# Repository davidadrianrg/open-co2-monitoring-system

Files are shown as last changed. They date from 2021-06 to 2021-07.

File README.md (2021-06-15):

# open-co2-monitoring-system
CO2 monitoring system using ESP8266 as microcontroller and MH-Z19C as CO2 sensor, the data collected will be send to the cloud through MQTT protocol. In the cloud server the data will be managed by Node-Red, stored in an InfluxDB database and plot using Grafana service.

## Installation

### Flashing the microcontroller
Clone the repository using the following command.

```bash
git clone https://github.com/davidadrianrg/open-co2-monitoring-system.git
```
Create your secret `keys.h` file inside the folder `co2-sensor`, add your mqtt address and credentials in it like this.

```c++
//Configuration secret variables for the CO2 sensor
char brokerIP[15] = "ADD YOUR BROKER IP";
int brokerPort = 1883; //Or set another different than the default one
char mqtt_username[20] = "ADD YOUR MQTT USERNAME";
char mqtt_password[16] = "ADD YOUR MQTT PASSWORD";
```

Flash your ESP8266 microcontroller using Arduino IDE with the `co2-sensor.ino` file.

### Cloud services deployment

In your cloud instance, first install docker if you do not have installed it yet.

```bash
sudo apt update && apt install docker
```

Create a `.env` file to add the environment variables to config the containers described in `docker-compose.yaml`. Add the following to the file.

```.env
GF_PATHS_DATA=/var/lib/grafana
GF_PATHS_LOGS=/var/log/grafana
GF_SECURITY_ADMIN_USER=YOUR_GRAFANA_USER
GF_SECURITY_ADMIN_PASSWORD=YOUR_GRAFANA_PASSWORD

INFLUXDB_USERNAME=YOUR_INFLUXDB_USER
INFLUXDB_PASSWORD=YOUR_INFLUXDB_PASSWORD

MOSQUITTO_USERNAME=YOUR_MOSQUITTO_USER
MOSQUITTO_PASSWORD=YOUR_MOSQUITTO_PASSWORD
```

Create and start the containers with the services (Mosquitto, Node-Red, InfluxDB and Grafana). In the main folder of the project type the following.

```bash
sudo docker-compose up -d
```

Enjoy your IoT system!

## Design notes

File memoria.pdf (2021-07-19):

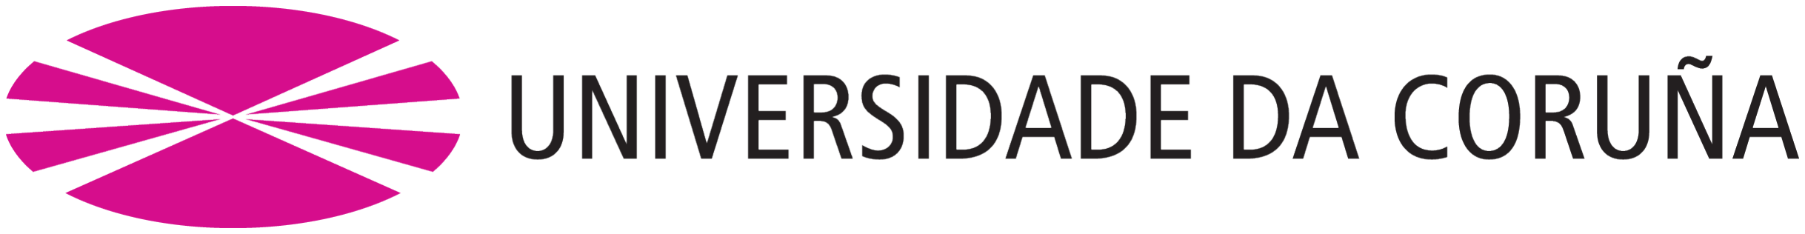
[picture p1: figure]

TÍTULO | DISENO DE SISTEMA DE MONITORIZACI ˜ | ON DE CALIDAD ´

### DEL AIRE EN LOCALES CON VENTILACION LIMITADA. ´

MASTER ´ | MASTER EN INFORM ´ | ATICA INDUSTRIAL Y ROB ´ | OTICA ´
ASIGNATURA | TRABAJO FIN DE MASTER (Nº 4538M01A001) ´
ALUMNO | DAVID ADRIAN RODR ´ | ÍGUEZ GARCÍA
TUTORES | FRANCISCO ZAYAS GATO
HECTOR QUINTI ´ | AN PARDO ´
FECHA | JUNIO DE 2021

## Índice

Resumen | 5
1 Introduccion´ | 6
1.1 Introduccion | ´ | 6
1.4.3 Computacion en la nube | ´ | 8
2 Monitorizacion de la calidad del aire | 10 ´
2.2 Principales parametros a controlar | ´ | 10
2.3 Sensores de medicion de CO2 | ´ | 11
3 Electronica y comunicaciones IoT | 15 ´
3.2 Esquema electronico de conexionado | ´ | 17
3.3 Programacion con Arduino | ´ | 18
3.3.3 Comunicacion UART con el sensor | ´ | 20
4 Arquitectura Cloud | 23

2

4.2.1 Arquitectura | 24
4.2.2 Docker | 24
4.3 Backend con Node-Red | 27
4.4 BBDD de series temporales | 29
4.5 Frontend | 30
4.5.1 Dashboards de visualizacion con Grafana | ´ | 30
4.5.2 Bot de notificaciones en Telegram | 31
5 Conclusiones y propuestas de mejora | 32
5.1 Conclusiones y resultados obtenidos | 32
5.2 Propuestas de mejora | 32
6 Referencias | 34
Anexos | 35
Presupuesto | 36

## Listado de figuras

1.1 Modelos de negocio de computacion en la nube | ´ | 9
2.1 Evolucion de la concentraci ´ | on de CO2 en un aula | ´ | 11
2.2 Tecnología NDIR en un sensor de CO2 | 12
3.1 Pinout NodeMCU V3 | 16
3.2 Esquema electronico de conexionado | ´ | | 17
3.3 Diagrama de Flujo del Programa Smart CO2 Sensor | 19
3.4 Portal Cautivo WiFiManager | 20
3.5 Conexionado bus UART | 20
3.6 Comunicacion MQTT | ´ | | 21
3.7 Carcasa impresa en 3D | 23
4.1 Arquitectura Cloud - Diagrama de despliegue | 25
4.2 Interfaces Docker | 25
4.3 Arquitectura Docker | 26
4.4 Diagrama de flujo en Node-Red | 28
4.5 Dashboard en Grafana | 30

3

4.6 Bot de alertas en Telegram | 31

## Listado de tablas

2.1 Comparativa de sensores comerciales de CO2 | 14
3.1 Pinout ESP-12F | 17
3.2 Conexionado de pines | 18
6.1 Listado de materiales empleados | 35
6.2 Presupuesto de prototipo de sensor inteligente de CO2 | 36

4

## Resumen

El presente Trabajo Fin de Master tiene por objetivo el dise ´ | no de un sistema de monitorizaci ˜ | on de ´
calidad del aire, a partir de hardware y sensorica de bajo coste. Se propone el uso de la plataforma ´
Arduino o similar junto con sensores de CO2, así como de algun sistema de centralizaci ´ | on local y/o en ´
la nube para almacenar y visualizar la informacion capturada. ´

## Resumo

O presente Traballo Final de Master ten por obxecto o dese ´ | no dun sistema de monitorizaci ˜ | on da ´
calidade do aire, a partir de hardware e sensorica de baixo custo. Proponse o uso da plataforma Arduino ´
ou similar xunto con sensores de CO2, así coma algun sistema de centralizaci ´ | on local e/ou na nube ´
para o almacenamento e visualizacion da informaci ´ | on recollida. ´

## Resumo

O objetivo desta Trabalho Final de Mestrado e projetar um sistema monitoramento da qualidade do ´ ar, com base em hardware e sensor de baixa custo. O uso da plataforma Arduino ou similar e proposto ´ em conjunto com sensores de CO2, bem como algum sistema de centralizaçao local e / ou na nuvem ˜ para armazenar e ver as informaçoes capturadas. ˜

## Abstract

The objective of this Master’s Thesis is to design an air quality monitoring system, based on low cost hardware and sensors. Using the Arduino platform or similar is proposed together with CO2 sensors, as well as some local and / or cloud centralization system to store and view the information captured.

5

## 1 Introduccion´

### 1.1 Introduccion´

El contexto socio-economico mundial ha cambiado recientemente a causa de la pandemia provo- ´
cada por el virus SARS-CoV-2 cuyo modo de infeccion y propagaci ´ | on es de tipo respiratorio. En esta ´
situacion, el control de la calidad del aire que respiramos en recintos cerrados ha cobrado especial ´ importancia para evitar la transmision del virus y asegurar el correcto desarrollo de la actividad social y ´ empresarial.
Este Trabajo Fin de Master pretende aportar una soluci ´ | on tecnol ´ | ogica y asequible enmarcada dentro ´
de la rama de desarrollo impulsada por los diferentes Estados para afrontar la recuperacion, la ´ | Digita-
lizacion e Industria 4.0 ´ | .
La propuesta tecnologica a desarrollar en esta memoria trata sobre el dise ´ | | | no de un sistema inteli- ˜
gente de monitorizacion de la calidad del aire bajo los principios del c ´ | | odigo libre y el hardware libre y de ´
bajo coste. Buscando con ellos el acceso a esta tecnología a escuelas, universidades, pequenas y me- ˜ dianas empresas, y demas espacios interiores que necesiten controlar la calidad de su aire interior para ´ con ello prevenir y mejorar la ventilacion de estos espacios y asegurar el correcto estado de salubridad ´ de sus instalaciones y de las personas que las frecuentan.

El desarrollo del proyecto se ha publicado de forma libre bajo licencia GNU General Public License
v3.0 que permite su modificacion y difusi ´ | on respetando su continuaci ´ | on como c ´ | odigo abierto al p ´ | ublico. ´
Puede accederse al repositorio publico a trav ´ | es de la siguiente referencia [ ´ | 8].

### 1.2 Objetivos

Los objetivos que se plantean para este Trabajo Fin de Master consisten en el desarrollo de un ´
sistema de monitorizacion de la calidad del aire mediante la utilizaci ´ | on de hardware y sensores de ´
bajo coste así como haciendo uso de servicios de software libre para el tratamiento, visualizacion y ´ almacenamiento de los datos.
De esta forma, se desarrollara una soluci ´ | on econ ´ | omica que permitir ´ | a a diferentes escuelas, oficinas ´
y otros recintos cerrados controlar en todo momento la concentracion de CO2 en el aire, con el objetivo ´
de mejorar la ventilacion de dichos recintos y reducir con ello las probabilidades de transmisi ´ | on de en- ´
fermedades respiratorias y el agotamiento que produce una insuficiente calidad en el aire que respiran las personas.

### 1.3 Alcance

El alcance de este Trabajo Fin de Master comprende el dise ´ | no de un sistema de monitorizaci ˜ | on de ´
la calidad de aire basado las siguientes tecnologías y procesos:
Analisis de los par ´ | ametros del aire a monitorizar. ´

Estudio de mercado y seleccion del mejor sensor calidad-precio. ´

6

Programacion y montaje del prototipo de sensor de CO2 inteligente mediante hardware de bajo ´ coste e impresion 3D. ´

Despliegue y configuracion de los servicios backend en la nube para la recogida, an ´ | alisis y trata- ´
miento de los datos enviados por el sensor.

Analisis de los resultados obtenidos y propuestas de mejora del producto de cara a una posible ´ version comercial del mismo. ´

### 1.4 Antecedentes

El sensor de CO2 inteligente de este proyecto aglutina el uso de diferentes tecnologías en un mismo producto, en concreto combina el uso de la plataforma Arduino para programacion y como estandarte ´ del hardware de bajo coste, el empleo de comunicaciones IoT que permiten interconectar gran cantidad
de objetos cotidianos a internet y la computacion en la nube como soluci ´ | on que permite acceder a ´
las ventajas del uso de servidores sin disponer de infraestructura propia, reduciendo notablemente los costes, limitandolos al pago por uso de los recursos. ´

### 1.4.1 Plataforma Arduino

Arduino es una plataforma de hardware-libre y codigo abierto utilizada para construir proyectos de ´
electronica y para el prototipado r ´ | apido de productos. La plataforma cuenta con una gran comunidad de ´
usuarios que respaldan el proyecto y lo alimentan con una amplia variedad de librerías y ports de otros microcontroladores a esta plataforma, como el caso de los microcontroladores para el IoT de Espressif Systems.

La empresa Arduino aporta valor al mercado en dos aspectos, en primer lugar, el desarrollo de placas PCB que contienen todo lo necesario para desarrollar prototipos de electronica a un coste muy ´
bajo, la mas popular es el modelo ´ | Arduino UNO lanzado inicialmente en su primera version en el a ´ | nõ
2010, aunque el primer modelo de la compan˜ía el Arduino Serie fue lanzado en 2005.

En segundo lugar, la compan˜ía se encarga del mantenimiento y desarrollo del popular IDE de Arduino que permite la programacion de todas su placas y las de otros fabricantes que hayan portado sus ´ librerías a este entorno de desarrollo. El lenguaje de programacion utilizado es una variante de C/C++ ´
que solo requiere un mínimo de dos funciones basicas para funcionar, la funci ´ | on´ setup que se ejecuta
una sola vez al encenderse la placa y la funcion´ loop que se repite constantemente mientras la placa este encendida. ´

Esta plataforma ha servido y sirve como base para muchos de los proyectos de electronica que han ´
surgido en los ultimos 10 a ´ | nos, incluido el descrito en esta memoria. ˜

### 1.4.2 Internet de las Cosas

El concepto de Internet de las Cosas o en ingles´ Internet of Things (IoT) surgio en el a ´ | no 1999 ˜
en el MIT en el campo de la identificacion por radiofrecuencia (RFID), pero hoy en d ´ | ía es un termino ´
mucho mas amplio que comprende gran cantidad de objetos que pueden ampliar sus funcionalidades ´ mediante una conexion a la red. En este sentido han salido al mercado todo tipo de dispositivos como ´ lavadoras, neveras, bombillas, termostatos, etc. denominados inteligentes que permiten su telegestion´ desde cualquier lugar a traves de internet. ´

7

El internet de las cosas presenta aplicacion en multitud de campos diferenciados, desde controlar ´ mediante sensores el campo en la agricultura para conseguir las condiciones idoneas de humedad, luz, ´
temperatura, etc. hasta sistemas mas complejos como el Autom ´ | ovil Conectado que cuenta con un gran ´
numero de sensores que env ´ | ían informacion en tiempo real sobre el estado del veh ´ | ículo (aceleracion, ´
velocidad, nivel de combustible, ubicacion, etc.). ´
En un mundo cada vez mas digital el auge del internet de las cosas contin ´ | ua su crecimiento de ´
forma exponencial, cada días mas dispositivos se conectan a la red por lo que la tecnolog ´ | ía debe seguir
avanzando para garantizar la seguridad de las comunicaciones y la mejora de las mismas, mediante nuevos protocolos y nuevos sistemas de telecomunicaciones como el 5G.

### 1.4.3 Computacion en la nube ´

Se entiende por computacion en la nube ´ | como un paradigma en el que se ofrecen servicios de
computo inform ´ | aticos mediante un modelo de negocio en el que se paga por uso, se solicita el uso de ´
recursos informaticos, principalmente almacenamiento de datos y capacidad de c ´ | omputo en un centro ´
de datos que se encuentran disponibles a traves de internet. ´

Dentro de este amplio concepto, existen otros tres que se han vuelto muy populares en los ultimos ´ anos: ˜

Infraestructura como servicio (IaaS), es el modelo de pago por uso de servicios informaticos de ´ procesamiento, almacenamiento y redes en los servidores de centros de datos del proveedor del servicio.

Plataforma como servicio (PaaS), es similar al IaaS pero con una capa superior de abstraccion, ´ ademas de la infraestructura, el servicio contratado ofrece otras herramientas como middlewares, ´ sistemas de Business Intelligence, sistemas de administracion de bases de datos y el sistema ´ operativo y diferentes aplicaciones o librerías que son necesarias para el despliegue de la aplicacion. ´

Software como servicio (SaaS), es un modelo de distribucion de software en el que el c ´ | odigo ´
y los datos se almacenan en un servidor en la nube y el usuario accede al servicio a traves de ´ internet. Normalmente el software puede ser consultado desde cualquier dispositivo a traves de ´ un navegador web.

Las aplicaciones mas modernas comienzan a ser desarrolladas entorno a estos paradigmas men- ´ cionados, y los modelos de negocio cambian de la venta de licencias tradicional a las suscripciones por uso del servicio (SaaS). La figura 1.1 muestra las diferencias entre los 3 conceptos anteriores.

### 1.4.4 Medidores de CO2 de referencia

Se ha tenido en cuenta como referencia para la realizacion de este proyecto, algunos de los medi- ´ dores de CO2 que se venden actualmente en el mercado.

Uno de ellos ha sido el modelo PCE-CMM 5 [9] de la empresa PCE Instruments, se trata de un modelo de medidor de CO2 con pantalla LCD y tecnología NDIR, muestra los valores de concentracion´ de CO2, temperatura y humedad por dicha pantalla pero no dispone de comunicacion con internet a ´ diferencia del prototipo a disenar en esta memoria. ˜

8

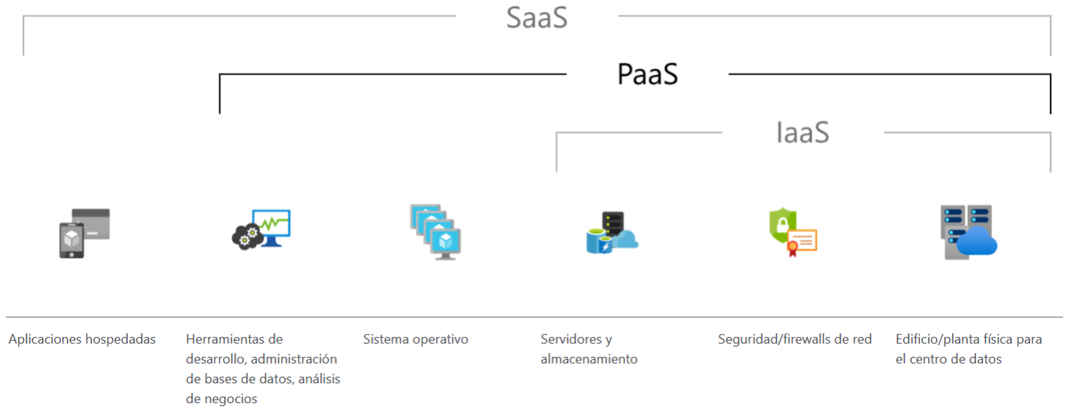
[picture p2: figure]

Figura 1.1: Modelos de negocio de computacion en la nube ´

En cuanto a medidores de referencia conectados a internet, existen varios proyectos que circulan por la red a cerca de medidores de CO2 con conexion por internet, entre ellos se ha tomado como ´
referencia especialmente el proyecto CODOS [12] de Miguel Angel Casanova que da una soluci ´ | on´

similar a la aquí planteada utilizando hardware de bajo coste y un portal cautivo para la visualizacion´
de los valores medidos, aunque sin utilizar los servicios cloud que se comentaran en el apartado ´ | 4.2.1
y que sera la mayor innovaci ´ | on del proyecto descrito en esta memoria. ´

### 1.5 Estructura del TFM

La estructura se divide en capítulos para tratar de alcanzar en ellos los objetivos descritos previamente.

En el capítulo 2 se presentan los diferentes motivos que impulsan este Trabajo Fin de Master en ´
relacion con la monitorizaci ´ | on de la calidad del aire y los beneficios que ´ | esta puede tener sobre la salud ´
de las personas, ademas se comentar ´ | an los principales par ´ | ametros a controlar y se realizar ´ | a un an ´ | alisis ´
del mercado de sensores de CO2 y la seleccion del m ´ | as apropiado para este proyecto. ´

En el capítulo 3 se describe el microcontrolador utilizado para la programacion del sensor inteli- ´
gente y los motivos de su eleccion, adem ´ | as se desarrollan las explicaciones y esquemas necesarios ´
para el conexionado de los diferentes componentes que conformaran dicho sensor inteligente. Tam- ´
bien se explicar ´ | a el funcionamiento del programa desarrollado para dicho microcontrolador y el tipo de ´
comunicaciones IoT utilizadas.

En el capítulo 4 se aborda la arquitectura del servidor en la nube necesario para la recogida, alma-
cenamiento y visualizacion de los datos enviados por el sensor, se explicar ´ | an los diferentes servicios y ´
metodos de despliegue utilizados. ´

En el capítulo 5 se comentan los resultados obtenidos a lo largo de todo el proyecto realizado, se proponen una serie de mejoras sobre el prototipo que podrían incluirse en un producto comercial final y se resumen las conclusiones mas importantes obtenidas de este proyecto. ´

9

## 2 Monitorizacion de la calidad del aire ´

### 2.1 Beneficios del control de la calidad del aire

La monitorizacion y control de la calidad de aire en locales cerrados presenta diferentes benefi- ´
cios para la salud de las personas, en particular se tratara dicha monitorizaci ´ | on en aulas de colegios, ´
institutos o universidades, pues se busca la utilidad del sistema proyectado como medida de monitori-
zacion del aire y prevenci ´ | on de enfermedades respiratorias como el ´ | COVID-19 en las instalaciones de
la Universidade da Corunã .
La informacion recogida en esta secci ´ | on ha sido obtenida del documento oficial elaborado por el ´
CSIC-IDAEA, Ministerio de Ciencia e Innovacion y Mesura ´ | [11] y plantea estrategias para indicar las
condiciones de ventilacion adecuadas en las aulas, as ´ | | í como una serie de características deseables en
los medidores de CO2 a utilizar para la monitorizacion de la calidad del aire. ´
La concentracion de CO2 en espacios interiores cerrados aumenta r ´ | | apidamente en presencia de ´
personas, que exhalan al respirar. La renovacion del aire con aire exterior reduce las concentraciones ´
de CO2 en el interior. Esto favorece la atencion y rendimiento escolar, ya que la exposici ´ | on a concen- ´
traciones de CO2 demasiado elevadas produce aletargamiento y dificulta la atencion. ´

Por ello es necesario garantizar la correcta renovacion del aire del aula para disminuir la concen- ´
tracion de CO2 y otras part ´ | | ículas infecciosas como los virus. Para medir la renovacion de aire en un ´
espacio cerrado se utiliza el termino ACH ´ | Air Changes per Hour que indica que en 1 hora entra en la
sala una cantidad de aire igual al volumen de la misma.

Una medida recomendable para el ACH es de 14 litros por persona y segundo que se puede transformar a renovaciones por hora mediante la siguiente expresion. ´

| ACH =

litros

persona·segundo · npersonas · 3600 seg h

- 0.001 m³ litros·Vsala

Teniendo en cuenta que la concentracion de CO2 es aproximadamente de 420 ppm en ambientes ´ exteriores, y que se entiende como de cierto riesgo sobrepasar los valores de 1000 ppm en un espacio cerrado, la figura 2.1 muestra un ejemplo de la variacion de CO2 en un aula con 21 alumnos y un ´
metodo de ventilaci ´ | on natural con ventilaci ´ | on cruzada (apertura de puertas y ventanas opuestas) que ´
es la que se presenta en la mayoría de las aulas.
Como conclusion obtenida de la gr ´ | afica vemos que utilizando adecuadamente la ventilaci ´ | on en el ´
momento oportuno se puede evitar sobrepasar el valor de riesgo de 1000 ppm de concentracion de ´
CO2. Teniendo esto en cuenta, el objetivo de este Trabajo de Fin de Master ser ´ | a desarrollar un sensor ´
de CO2 inteligente que notifique a los usuarios de la sala mediante graficas en tiempo real y un chat ´
de mensajería, de esta forma podra preveerse el aumento de la concentraci ´ | on de CO2 y actuar con ´
anterioridad para estabilizar dicha concentracion en valores saludables para las personas. ´

### 2.2 Principales parametros a controlar ´

Como se ha comentado en el apartado 2.1 la medicion de la concentraci ´ | on de CO2 es el principal ´
parametro a controlar en un sistema de monitorizaci ´ | | on de la calidad de aire, pues permite calcular a ´
partir de ella las renovaciones hora del espacio.

10

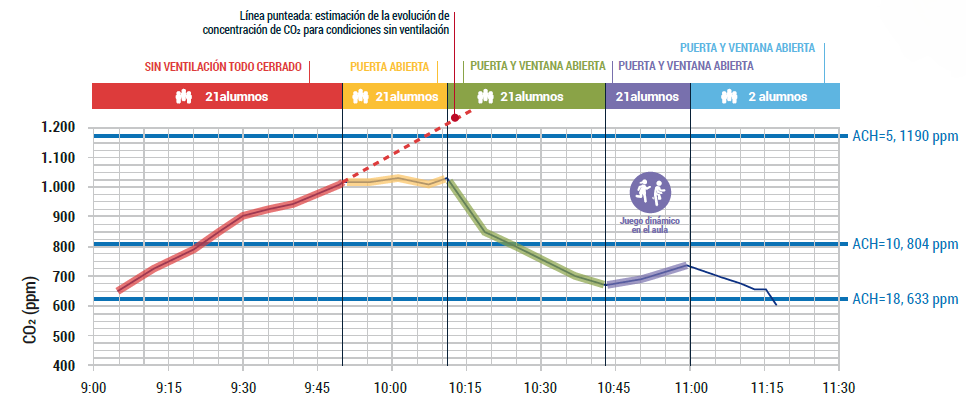
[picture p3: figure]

Figura 2.1: Evolucion de la concentraci ´ | on de CO2 en un aula ´
Como parametros adicionales interesantes que afectan al confort en un espacio interior se podr ´ | ía
realizar la medicion de las condiciones de temperatura y humedad del ambiente, y de esta forma tratar ´
de garantizar el compromiso ideal entre la ventilacion realizada y el confort t ´ | ermico para las personas, ´
evitando, por ejemplo, una ventilacion natural excesiva que provoque una fuerte ca ´ | ída en la temperatura
de la sala.

Tambien es conveniente destacar que el CO2 no se degrada con el tiempo, mientras que los virus ´
en aire sí, por lo que las concentraciones de virus en aire decreceran m ´ | as r ´ | apidamente que las de CO2. ´
La diferencia depende de varios factores ambientales, tales como radiacion UV o temperatura. Por lo ´
que utilizar la concentracion de CO2 como medida para cuantificar las necesidades de ventilaci ´ | on de ´
un espacio es conservador y permite garantizar la correcta calidad del aire en la sala.

Con referencia a lo aquí mencionado se estudiara el mercado de sensores de CO2 que existe ´
en la actualidad y se tratara de seleccionar el que mejor se adapte en relaci ´ | on calidad-precio a las ´
características mencionadas en el apartado 2.3.

### 2.3 Sensores de medicion de CO2 ´

En este apartado se realizara un estudio de mercado acerca de los diferentes sensores de CO2 ´ existentes para desarrollo/prototipado analizando sus características tanto para el tipo de medicion de ´ CO2 que realizan como sus interfaces de comunicaciones con el microcontrolador y el rango de precio
en el que se situan. Estas caracter ´ | ísticas seran comparadas con las recomendadas en el art ´ | ículo [11]
para medidores de CO2 en aulas y son las siguientes:

Capacidad de proporcionar los datos sin procesar descargables en archivo .txt, .xls, .csv o similar.

Resolucion temporal de al menos un dato por minuto ´

Pantalla que muestre los niveles de CO2 en tiempo real

Uso de tecnología NDIR (del ingles nondispersive infrared) ´

Coste entre 100 y 300 C

11

Estas características antes mencionadas hacen referencia a un medidor de CO2 comercial, el ob-
jetivo de este proyecto es aportar una solucion diferente y m ´ | as innovadora, a ´ | nadiendo conectividad al ˜
sensor de CO2 y un conjunto de servicios en la nube para el procesado, almacenamiento y visualizacion´ en tiempo real de los valores de concentracion medidos. Por lo que aunque han de tenerse en cuenta ´ las características mencionadas, no se seguiran al pie de la letra a la hora de seleccionar el sensor a ´ utilizar.

Del estudio de mercado realizado se han seleccionado los sensores de CO2 mas representativos, ´
listando en la tabla 2.1 sus diferentes características tecnicas para su comparaci ´ | on. ´

Existen principalmente 2 tipos de tecnologías que permiten medir la concentracion de CO2 en al ´ aire ambiente, se trata de las tecnologías NDIR (Non Dispersive Infrared) y MOS (Metal Oxide Semi-
conductor) que se describiran a continuaci ´ | on. ´

La tecnología NDIR realiza la medicion directa del CO2 mediante un haz de luz infrarroja en el interior ´ de la camara de aire del sensor, el CO2 absorbe una determinada longitud de onda del infrarrojo y de ´ esta forma el detector de infrarrojos con el que cuenta el sensor es capaz de filtrar el resto de longitudes de onda de la luz y medir la intensidad de la longitud de onda que absorbe la molecula de CO2 para ´
con ello obtener su concentracion. La figura ´ | 2.2 muestra el proceso descrito.

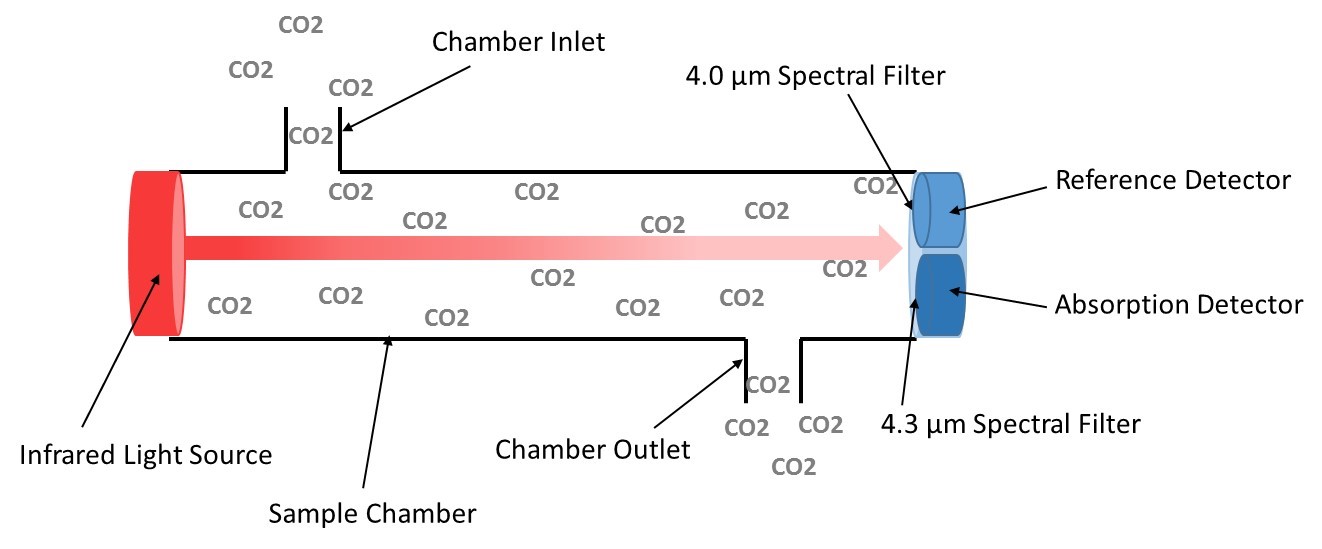
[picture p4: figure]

Figura 2.2: Tecnología NDIR en un sensor de CO2

En cambio la tecnología MOS se basa en la medicion de los compuestos org ´ | anico vol ´ | atiles (VOC) ´
del aire por oxidacion de un semiconductor de ´ | oxido de metal, y con ellos pueden calcular de forma ´
indirecta la concentracion de CO2 en el aire, por lo que su precisi ´ | on es m ´ | as baja, y depende mucho ´
de los valores de temperatura y humedad a la hora de realizar dicho calculo lo que implica que deben ´ acompanarse de un sensor externo de Tª y Humedad que suministre dichos valores al sensor MOS. ˜
Las ventajas de los sensores MOS es que suelen ser mas baratos que los NDIR, de menor tama ´ | nõ
y menor consumo. En cambio los sensores NDIR ofrecen una medida del CO2 mas precisa aunque ´
tambien su consumo, coste y tama ´ | no es mayor. ˜

Dado que entre las características que se tendran en cuenta para este proyecto el consumo no ´ es relevante pues el microcontrolador WiFi que se utilizara para comunicar los datos tiene un elevado ´
consumo debido al protocolo WiFi, se optara entonces por dise ´ | nar un medidor de CO2 inteligente ˜
con alimentacion directa de la red. En el caso de optar por soluciones inal ´ | ambricas con bater ´ | ía sería
necesario utilizar otro protocolo de menor consumo como Zigbee o BLE (Bluetooth Low Energy).

12

El tamano, aunque importante para un futuro producto final, no es demasiado relevante en este ˜ prototipo y tampoco sería crítico en un producto final, ya que se busca un producto que se ubicara de ´ forma estatica en una sala y no es necesaria demasiada portabilidad del mismo. ´

El coste sí es importante pues en general para la monitorizacion de la calidad de aire de una escuela ´ o universidad sería necesario contar con al menos uno por aula, por lo que reducir al maximo los costes ´ supondría una mayor posibilidad de aceptacion del producto hacia este segmento de clientes objetivo. ´

La precision en la medici ´ | on juega un papel clave a la hora de seleccionar el tipo de tecnolog ´ | ía del
sensor, lo que se busca es la prevision de la concentraci ´ | on de CO2 con anterioridad y un correcto control ´
de su evolucion en funci ´ | on de la ventilaci ´ | on realizada por lo que es necesaria una buena precisi ´ | on que ´
garantice una correcta correlacion entre la concentraci ´ | on y el uso de la ventilaci ´ | on. ´

Teniendo en cuenta todas estas características descritas y el estudio de mercado realizado y recogido en la tabla 2.1 se ha decidido seleccionar para este proyecto el modelo de sensor de tecnología NDIR MH-Z19c de la marca Winsen pues permite asegurar una correcta relacion calidad-precio. ´

13

Fabricante Modelo Tecnología Rango Efectivo Precisión Interfaz Tiempo de respuesta Sensores Precio

Amphenol T6713 NDIR 400-2000 ppm ± (25 ppm + 3 %) UART, I2C, PWM <180 s (90 %) CO2 48.19 - 70.99 C

Amphenol T6713-5K NDIR 400-5000 ppm ± (30 ppm + 3 %) UART, I2C, PWM <180 s (90 %) CO2 51.46 - 70.99 C

Cubic CM1106-C NDIR 400-5000 ppm ± (50 ppm + 5 %) UART, I2C, PWM 30 s CO2

Cubic CM1106SL-NS NDIR 400-5000 ppm ± (50 ppm + 5 %) UART 120 s CO2

Gas Sensing Sol. COZIR-AH-E-1 NDIR 400-10000 ppm ± (30 ppm + 3 %) UART 30 s (90 %) CO2, H, T 73.78 - 100.14 C

Gas Sensing Sol. COZIR-LP-5000 NDIR 400-5000 ppm ± (30 ppm + 3 %) UART 30 s (90 %) CO2 63.41 - 86.06 C

Honeywell CRIR M1 NDIR 400-2000 ppm ± (40 ppm + 3 %) UART 120 s CO2 39.48 - 51.34 C

SenseAir S8 LP NDIR 400-2000 ppm ± (40 ppm + 3 %) UART, PWM <120 s (90 %) CO2 23.17 - 36.42 C

SenseAir Sunrise NDIR 400-5000 ppm ± (30 ppm + 3 %) UART, I2C 16 s CO2 44.84 C

Sensirion SCD-41 NDIR 400-5000 ppm ± (40 ppm + 5 %) I2C 60 s (63 %) CO2, H, T 42.94 C

Sensirion SCD-30 NDIR 400-10000 ppm ± (30 ppm + 3 %) UART, I2C, PWM 20 s (63 %) CO2, H, T 30.57 - 44.47 C

Winsen MH-Z19B NDIR 400-5000 ppm ± (50 ppm + 5 %) UART, PWM <120 s (90 %) CO2 18.61 C

Winsen MH-Z19C NDIR 400-5000 ppm ± (50 ppm + 5 %) UART, PWM <120 s (90 %) CO2 17.09 C

ZyAura (Radiant) ZG09 NDIR 400-10000 ppm ± (50 ppm + 3 %) UART, I2C, PWM 60s CO2 27.11 C

Adafruit AMS CCS811 MOS 400-8192 ppm ± 2 % I2C 250ms - 60s CO2 24 C

Sparkfun SEN-16531 MOS 400-60000 ppm ± 1 % I2C 1s CO2 20 C

Keystudio AMS CCS811 MOS 400-8192 ppm ± 2 % I2C 250ms - 60s CO2 15 C

Sparkfun SEN-14348 MOS 400-8192 ppm ± 2 % I2C 250ms - 60s CO2, H, T 29 C

Tabla 2.1: Comparativa de sensores comerciales de CO2

14

### 2.3.1 Sensor MH-Z19C

El sensor de la empresa China Zhengzhou Winsen Electronics Technology Co., Ltd en concreto el modelo MH-Z19c es el que se ha seleccionado dada su alta relacion calidad-precio. ´

Se trata de un sensor que utiliza la tecnología NDIR, con un rango efectivo entre 400 ppm y 5000
ppm, que cubre perfectamente la aplicacion para la que est ´ | a destinado, lo mismo sucede con la pre- ´
cision ± (50 ppm + 5 %), la interfaz de comunicaci ´ | on es UART y cuenta con multitud de librer ´ | ías que
facilitan el desarrollo de codigo para el entorno Arduino, como se explicar ´ | a en la secci ´ | on´ 3.3.3, ademas´
tambien presenta la interfaz de comunicaci ´ | on PWM aunque no se usar ´ | a en este proyecto. ´
Como puntos mas negativos del sensor es que s ´ | olo cuenta con sensor de CO2, no incluye de hume- ´
dad y temperatura, pero puede calcular la temperatura de forma indirecta en funcion de la concentraci ´ | on´
de CO2 medida. Ademas el tiempo de respuesta del sensor es de 120 segundos, el doble de lo reco- ´
mendado en 2.3, este ser ´ | a el par ´ | ametro limitante a la hora de seleccionar el tiempo de muestreo en el ´
programa del microcontrolador.

En general sopesando todas las características y teniendo muy en cuenta su principal ventaja, el
precio, es el sensor NDIR mas barato del mercado, apenas unos 17,09 ´ | C, es el sensor ideal para un
producto que pretende dar una solucion econ ´ | omica, innovadora y precisa para el control de la calidad ´
de aire en las aulas de escuelas y universidades.
Una documentacion m ´ | as extensa acerca de las caracter ´ | ísticas tecnicas del sensor puede encon- ´
trarse en la ficha tecnica del fabricante [ ´ | 6].

## 3 Electronica y comunicaciones IoT ´

### 3.1 Placa de desarrollo NodeMCU V3

La placa electronica PCB encargada de hacer “inteligente” el sensor de CO2 seleccionado en el ´ apartado 2.3.1, se trata de una placa NodeMCU V3 que es una plataforma IoT de codigo abierto y ´ hardware libre que incluye el SoC ESP8266 de la empresa Espressif Systems.

NodeMCU surgio inicialmente como un kit de desarrollo para el prototipado de dispositivos ´ | IoT me-
diante el lenguaje de scripting LUA, posteriormente al desarrollo de la portabilidad del core de Arduino
para ESP8266, NodeMCU amplio su compatibilidad con ´ | este entorno de desarrollo, que es el que utili- ´
zaremos para este proyecto como se describe en la seccion´ 3.3.

La placa cuenta con el SoC ESP8266 como chip principal, con sus correspondientes GPIOs ma-
peados a las entradas/salidas digitales y la entrada analogica de la placa que se mencionar ´ | an m ´ | as en ´
detalle en el apartado 3.1.1, cuenta tambien con una interfaz micro USB para su programaci ´ | on y ali- ´
mentacion, adem ´ | as del regulador de tensi ´ | on que permite alimentarlo a 5V desde el micro USB o hasta ´
12V desde el pin Vin. Cuenta tambien con un pin de salida ´ | VU conectado directamente a la tension del ´
micro USB por lo que podría resultar muy util para alimentar directamente sensores o actuadores que ´ funcionen a 5V en lugar de los 3.3V de operacion del SoC. ´

Como conversor de USB a interfaz serie para programar el SoC la placa incluye el chip FTDI modelo CH340, la siguiente figura 3.1 muestra el pinout de la placa.

15

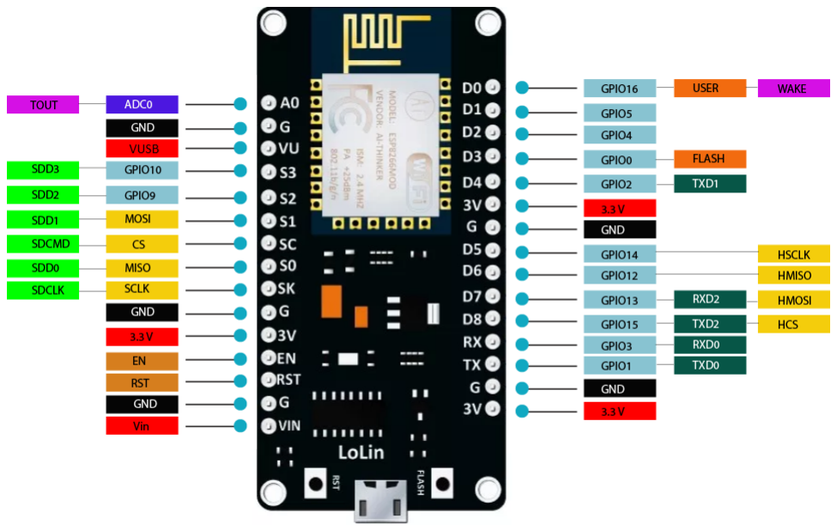
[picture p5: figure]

Figura 3.1: Pinout NodeMCU V3

### 3.1.1 Microcontrolador ESP8266

El microcontrolador ESP8266 se ha convertido en uno de los SoC (System on Chip) mas populares ´ en el sector del Internet de las Cosas, desde su lanzamiento en el ano 2014 por la empresa china ˜ Espressif Systems, numerosos productos comerciales lo han incorporado como base para dispositivos inteligentes, y existen en internet gran cantidad de soluciones profesionales y maker que utilizan este microcontrolador como base para sus proyectos.

Algunas de las características que han garantizado su exito son: ´

Conexion WiFi con stack TCP/IP completo. ´

Programacion desde el entorno de Arduino. ´

Muy bajo coste, entre 1-3 C dependiendo del modelo.

Diferentes versiones con mejoras en memoria y numero de GPIOs. ´

Lo incorporan una gran variedad de kits de desarrollo.

El modelo que incorpora la placa de desarrollo NodeMCU V3 utilizada para este proyecto es el ESP-12F desarrollado por la empresa china Ai-Thinker Technology el cual encapsula el chip ESP8266 core.

Los pines que incluye el chip mencionado son los que recoge la tabla 3.1.

El tipo de empaquetado que utiliza es SMD22 y la memoria flash de la que dispone es de 32 MB
(MegaBytes). Para una mayor descripcion de las caracter ´ | ísticas del chip acuda la ficha tecnica del ´
fabricante [5].

16

Tipo de pin | Numeracion | Unidades ´
GPIO | GPIO0 - GPIO16 | 16
UART | TX0 - RX0 | 1 (2 pines)
ADC (10bit) | A0 | 1
SPI | GPIO12(HMISO), GPIO13(HMOSI), GPIO14(HSCLK), GPIO15(HCS) | 1 (4 pines)
RESET | RST | 1
ENABLE | EN | 1
POWER | GND-VCC | 1 (2 pines)

Tabla 3.1: Pinout ESP-12F

### 3.2 Esquema electronico de conexionado ´

La configuracion de hardware necesaria para llevar a cabo el proyecto de sensor de CO2 inteligente, ´
requiere la utilizacion de los siguientes m ´ | odulos hardware interconectados: ´

Placa de desarrollo NodeMCU V3

Sensor de CO2 modelo Winsen MH-Z19c

Modulo de alimentaci ´ | on MB-102 ´
La utilizacion del m ´ | odulo de alimentaci ´ | on, aunque no es imprescindible para este proyecto al contar ´
con el pin VU se ha decidido utilizar para aportar una mayor conectividad en la alimentacion (interfaz ´
USB y jack) y la disponibilidad de un boton para encender/apagar la alimentaci ´ | on. Adem ´ | as este m ´ | odulo ´
permite salida de voltaje a 5V y 3,3V por lo que es compatible con todo tipo de sensores y actuadores que puede manejar el microcontrolador ESP8266.

El esquema de conexionado de los componentes sería el indicado por la figura 3.2

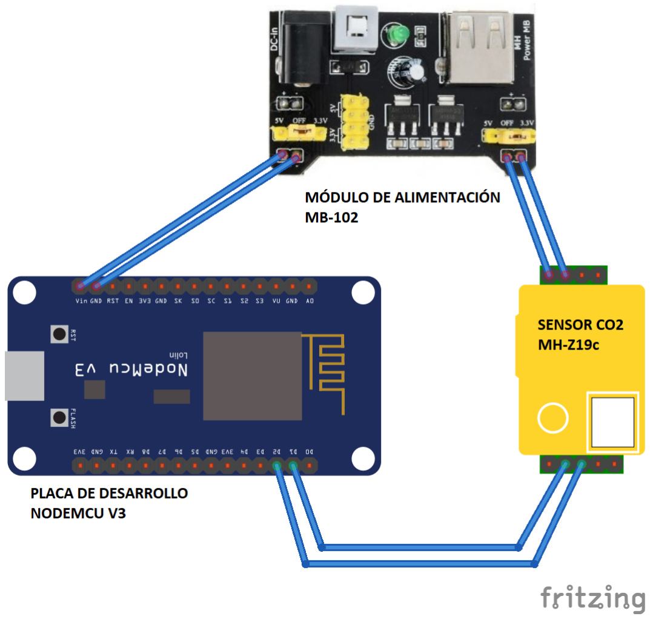
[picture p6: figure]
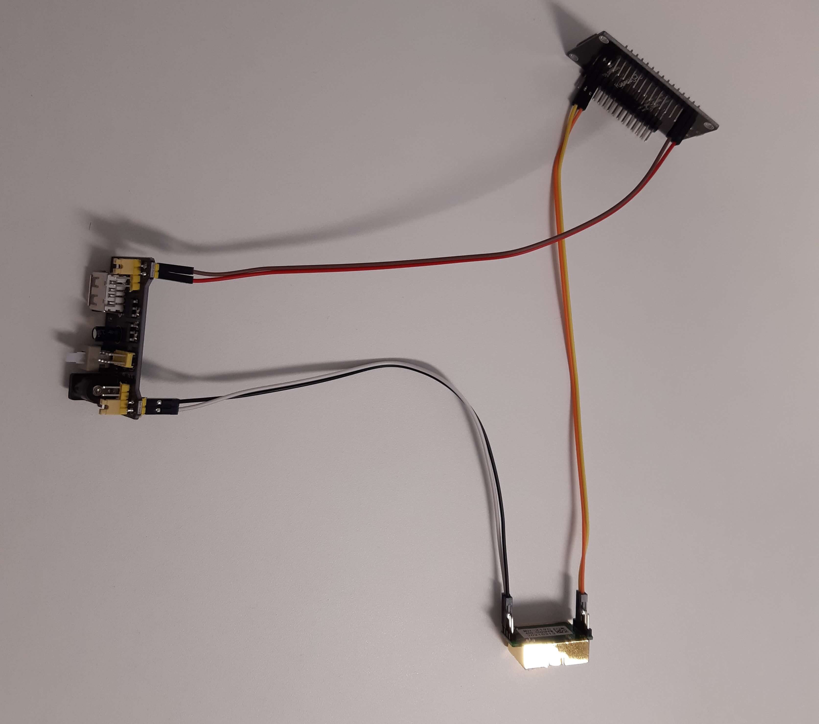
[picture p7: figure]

Figura 3.2: Esquema electronico de conexionado ´

El modulo de alimentaci ´ | on presenta dos salidas configurables a 5V o 3,3V mediante un conector ´
jumper, en este caso se configuraran las dos a 5V pues el regulador de voltaje de la placa NodeMCU ´

17

requiere como mínimo 5V y la alimentacion por el pin ´ | Vin se realiza a traves de dicho regulador. Por ´
tanto el conexionado queda como indica la tabla 3.2.
Modulo | Pines | M ´ | odulo | Pines ´
MB-102 | +, - (5V) | NodeMCU | Vin, GND
MB-102 | +, - (5V) | MH-Z19c | Vin, GND
NodeMCU | D1(TX), D2(RX) | MH-Z19c | RX, TX

Tabla 3.2: Conexionado de pines

### 3.3 Programacion con Arduino ´

### 3.3.1 Funcionamiento

La programacion del microcontrolador se llevar ´ | a a cabo mediante el framework de Arduino, pues el ´
core del microcontrolador que se ha utilizado, el Espressif ESP8266, ha sido portado a Arduino con una compatibilidad muy alta en cuanto a librerías y funcionalidades en relacion con el Arduino Core. Por ´ ello, las facilidades de programacion de este microcontrolador lo han convertido en todo un referente ´ para el desarrollo de dispositivos en el sector del Internet de las cosas.

Para la programacion que se ha llevado a cabo en este prototipo de sensor de CO2 y Temperatura ´ inteligente se ha tenido en cuenta la inclusion de las siguientes funcionalidades: ´

Comunicacion serie con el sensor mediante UART. ´

Comunicacion serie con el PC para depuraci ´ | on de c ´ | odigo. ´
Configuracion din ´ | amica de las credenciales WiFi. ´
Funcion de autocalibraci ´ | on del sensor activada. ´
Conexion con broker MQTT y reconexi ´ | on en caso de p ´ | erdida de la comunicaci ´ | on. ´

Toma de medidas y envío de datos por MQTT en bucle cada tiempo de muestreo.

La figura 3.3 muestra un diagrama de flujo del programa co2-sensor.ino. (https://github.com/davidadrianrg/open-co2-monitoring-system/blob/master/co2-sensor/co2-sensor.ino)

### 3.3.2 Librería WiFiManager

Uno de los problemas que presentan la programacion del microcontrolador ESP8266 es la confi- ´
guracion de las credenciales de acceso a internet, de conexi ´ | on WiFi con el router, habitualmente esta ´
configuracion suele establecerse directamente en el propio fichero del programa con el consecuente ´ inconveniente de que en caso de modificarse el ssid o la contrasena de la red WiFi, o simplemente de ˜ mover el microcontrolador a un lugar con otra red, es necesario volver a flashear el programa con las nuevas credenciales de conexion WiFi. ´

Para solucionar el problema mencionado, y con el objetivo de aproximarnos mejor a un producto
comercial, se implementara en el programa la librer ´ | ía WiFiManager[10] que permite la configuracion´
dinamica de las credenciales WiFi sin modificar el programa. ´

Los pasos que sigue la librería para establecer la conexion WiFi son: ´

18

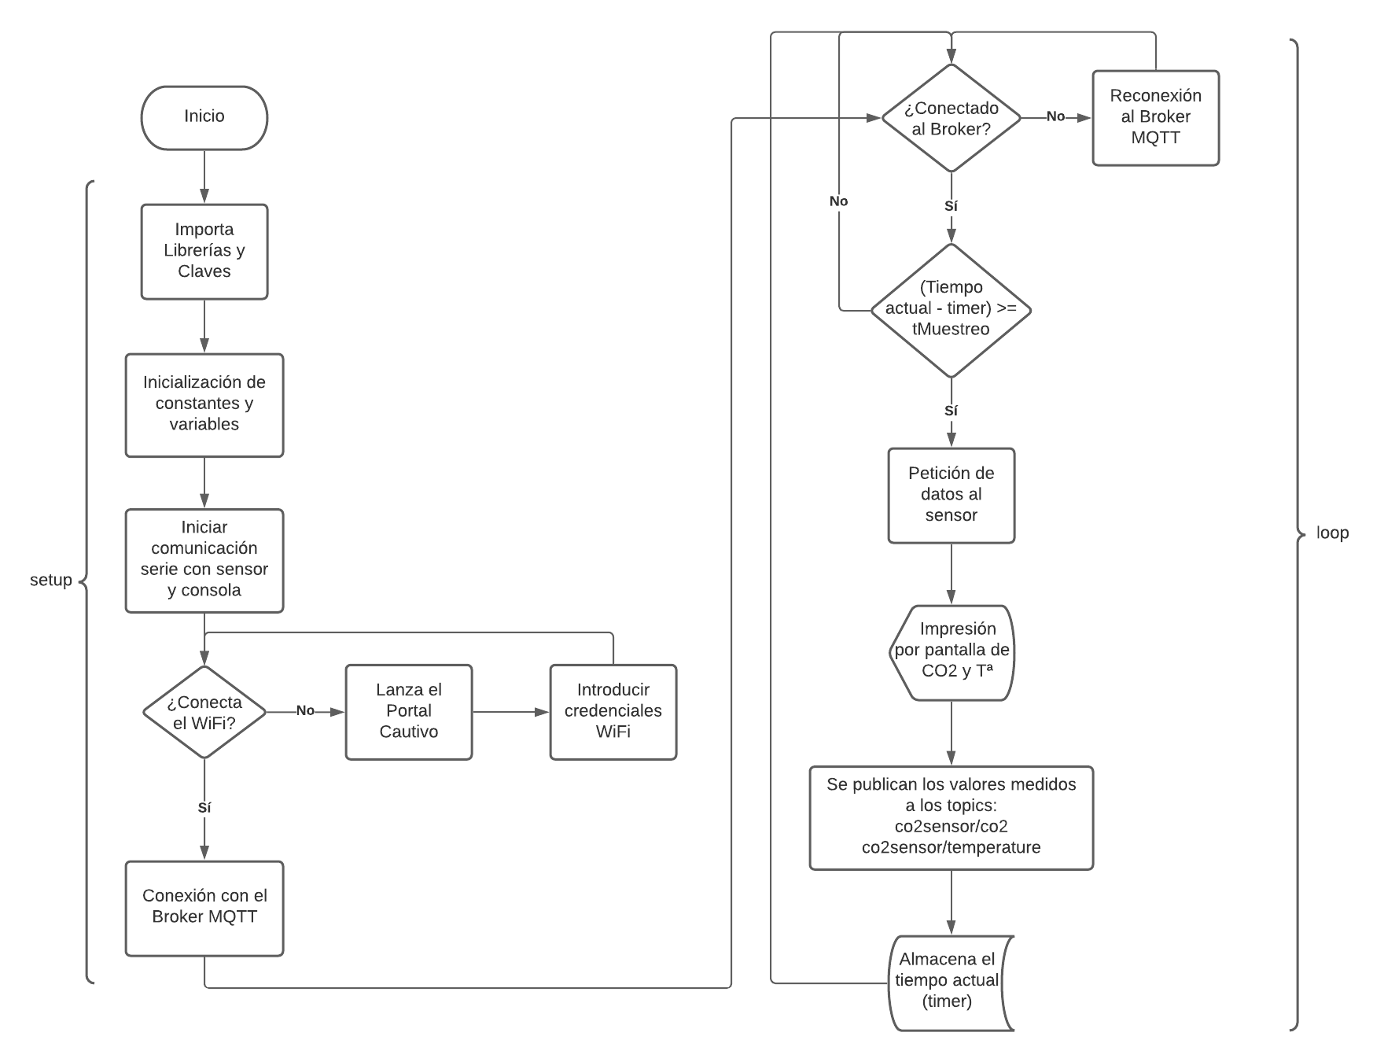
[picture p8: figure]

Figura 3.3: Diagrama de Flujo del Programa Smart CO2 Sensor

1. Comprueba que se puede realizar la conexion WiFi con las credenciales almacenadas en la me- ´ moria EEPROM.
2. Si la conexion no es posible, levanta un portal cautivo en la direcci ´ | on´ 192.168.4.1 y con el ssid
de la WiFi generada que se haya indicado en el codigo, en este caso ´ | Smart-CO2-Sensor.
3. Al acceder a la direccion indicada, el portal cautivo mostrar ´ | a una p ´ | agina web que permitir ´ | a intro- ´
ducir las credenciales WiFi de la nueva red, como muestra la figura 3.4.
4. Tras introducir las credenciales correctamente el microcontrolador las almacenara en la memo- ´
ria EEPROM y se reiniciara, conect ´ | andose en el pr ´ | oximo arranque a la red WiFi que hayamos ´
indicado.

De esta forma puede implementarse una solucion sencilla al problema antes comentado, la imple- ´
mentacion de un portal cautivo es una forma de comunicaci ´ | on con el usuario que utilizan una gran ´
cantidad de productos comerciales en el ambito de la ´ | domotica IoT ´ | . En productos comerciales termi-
nados permite ademas de configurar las credenciales WiFi, configurar otros par ´ | ametros como podr ´ | ía
ser las configuraciones MQTT, o el tiempo de muestreo del sensor en el caso del producto de este proyecto.

19

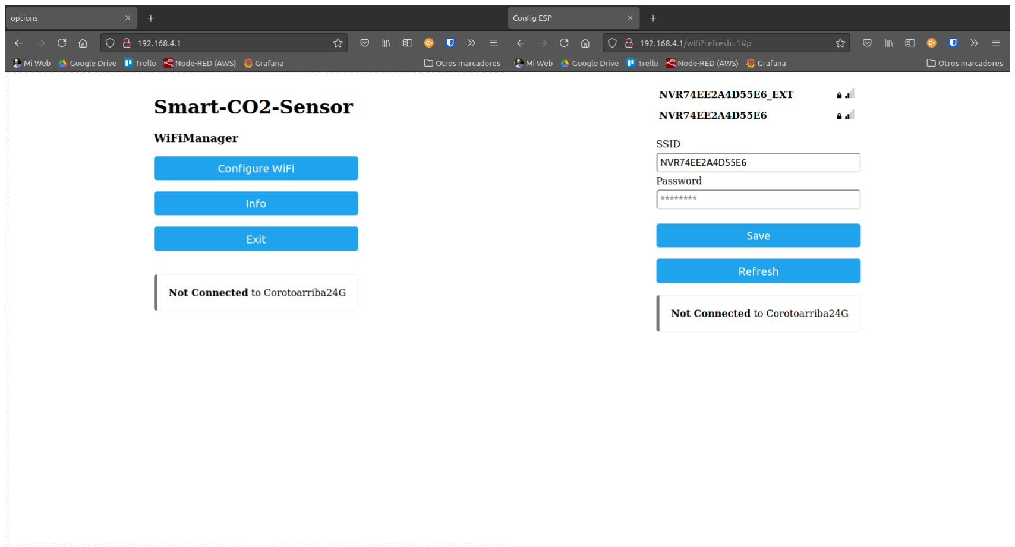
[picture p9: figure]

Figura 3.4: Portal Cautivo WiFiManager

### 3.3.3 Comunicacion UART con el sensor ´

La comunicacion entre el microcontrolador y el sensor para obtener los valores registrado por ´ | | | | el ´
durante la medida, concentracion de CO2 y temperatura, se llevar ´ | a a cabo mediante el protocolo de ´
comunicacion serie UART. ´

UART son las siglas de Universal Asynchronous Receiver Transmitter, se trata de un protocolo de tipo asíncrono, es decir no se comparte la frecuencia de reloj a traves del bus de comunicaciones si ´
no que emisor y receptor deben conocer de antemano la velocidad de transmision de la informaci ´ | on´
en el bus, ademas se trata de un protocolo serie por lo que los bits de datos se transmiten de forma ´
secuencial a traves de un ´ | unico cable de datos, adem ´ | as el tipo de comunicaci ´ | on es ´ | half-duplex por
lo que la comunicacion aunque es bidireccional solo puede darse en un sentido al mismo tiempo, los ´
cables que conformaran la transmisi ´ | on son llamados RX y TX y deben cruzarse en la conexi ´ | on entre ´
los diferentes nodos, como muestra la figura 3.5, una descripcion m ´ | as detallada de la arquitectura de ´
funcionamiento de este protocolo puede encontrarse en [4].

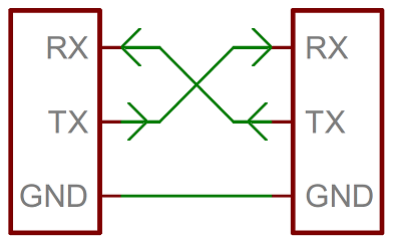
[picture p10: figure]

Figura 3.5: Conexionado bus UART

Para una mayor facilidad en la comunicacion entre el microcontrolador y el sensor se utilizar ´ | a la ´

20 librería MH-Z19 [3], cuya API implementa una interfaz de comunicacion m ´ as sencilla, en lugar de esta- ´ blecer la comunicacion de forma directa con el sensor mediante UART. ´

De esta forma, como se puede leer en el codigo de Arduino mencionado en ´ | 3.3.1 se utilizaran los ´
pines 4 y 5 de la placa NodeMCU como pines RX y TX respectivamente, para ello se hara uso de la ´ librería SoftwareSerial incluida en el core de Arduino. Esta librería permite establecer una comunicacion´ serie mediante software, utilizando otros pines que no hayan sido configurados mediante hardware
para utilizar la comunicacion UART, la raz ´ | on de realizar la comunicaci ´ | on de esta forma es la de poder ´
disponer de la comunicacion hardware UART de la placa para comunicar con la salida por consola al ´
ordenador mediante el USB y así realizar la depuracion del c ´ | odigo programado. ´

La velocidad de comunicacion a la que el microcontrolador se comunica con el sensor se ha estable- ´ cido en 9600 bps y la frecuencia de muestreo se ve limitada por la capacidad de respuesta del sensor, de la ficha tecnica del fabricante se obtiene que el tiempo de respuesta del sensor ante cambios en el ´ valor medido es de 120 segundos por lo que la frecuencia de muestreo que seleccionemos debe ser mayor o igual a este valor, por lo que se selecciona un tiempo de muestreo de 120 segundos para la lectura de los valores de concentracion de CO2 y Temperatura. ´

### 3.3.4 Envío de datos por MQTT

En el campo del Internet de las cosas uno de los protocolos mas utilizados para transmitir informa- ´
cion entre dispositivos es el protocolo ´ | MQTT, se trata de un protocolo de tipo publicacion/suscripci ´ | on, ´
los diferentes dispositivos se suscriben y publican mensajes a un broker central que es el que gestiona los diferentes clientes y los paquetes que se envían. Se trata de un protocolo de envío de mensajes muy ligero por lo que es ideal para dispositivos IoT de bajos recursos y la comunicacion se establece ´
sobre la pila TCP/IP. Una informacion m ´ | as extensa sobre el funcionamiento de este protocolo se puede ´
encontrar en la pagina web oficial de la organizaci ´ | on[ ´ 7].

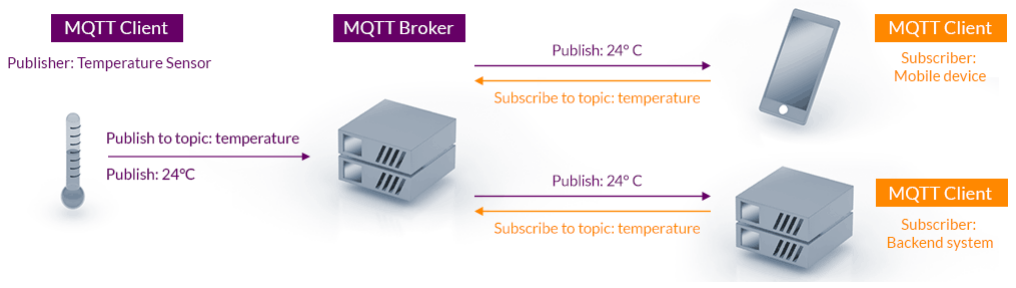
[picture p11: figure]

Figura 3.6: Comunicacion MQTT ´

Tomando la figura 3.6 como ejemplo para la transmision de informaci ´ | on de un sensor, el caso del ´
sensor de CO2 de este proyecto sigue el mismo patron, el sensor registrar ´ | a los valores de concentraci ´ | on´
de CO2 y de Temperatura cuando se lo pida el microcontrolador y este los publicar ´ | a al ´ | broker MQTT
instalado en el servidor, los topics (canales utilizados para identificar la informacion publicada) emplea- ´ dos para el sensor son co2sensor/co2 y co2sensor/temperature respectivamente, como se explicará
en el capítulo 4.2.1, el Backend del servidor se suscribira tambi ´ | en al broker MQTT para recibir el valor ´
de la concentracion de CO2 y la Temperatura y los almacenar ´ | a en la base de datos. ´
La programacion de la comunicaci ´ | on MQTT mediante el entorno Arduino se puede realizar con dife- ´
rentes librerías, pero la mas utilizada es la librer ´ | ía PubSubClient[2] que es la que se ha implementado

21 para el sensor de CO2 de este proyecto. Para establecer la comunicacion con el broker es necesario ´
conocer la direccion IP, el puerto y el usuario y contrase ´ | na configurados para el broker, ˜ | esta configura- ´
cion se ha de incluir en el script que ejecutar ´ | a el microcontrolador, para evitar introducir las credenciales ´
en plano en el fichero principal, se crea un fichero keys.h con las mismas, el cual no se publicara en ´
el repositorio, dicho fichero sera importado en el script principal, ´ | | co2-sensor.ino, (https://github.com/davidadrianrg/open-co2-monitoring-system/blob/master/co2-sensor/co2-sensor.ino) utilizando la siguiente
instruccion. ´

#include "keys.h"

La funcion´ callback, encargada de ejecutar acciones al recibir un mensaje en los topics suscritos, no se ha implementado pues en este prototipo solo se busca que el sensor mida los valores de ´
concentracion de CO2 y de Temperatura buscados. En un producto final podr ´ | | | ía implementarse dicha
funcionalidad y que el sensor se suscriba, por ejemplo, a un topic de configuracion donde se le pue- ´
dan cambiar ciertos parametros de la configuraci ´ | on a trav ´ | es de MQTT, como podr ´ | ía ser el tiempo de
muestreo.

### 3.4 Carcasa impresa en 3D

Con el objetivo de albergar todos los componentes electronicos y dar una primera aproximaci ´ | on al ´
aspecto de un producto final, se ha modelado una carcasa en tres dimensiones adaptada a las carac-
terísticas de los 3 modulos que componen el sistema, el m ´ | odulo de alimentaci ´ | on, el microcontrolador ´
NodeMCU V3, el sensor de CO2 MH-Z19C y los cables dupont necesarios para las conexiones entre ellos.
Entre las características a tener en cuenta para el diseno de la carcasa est ˜ | an: ´

Las dimensiones de cada modulo. ´

La posible ubicacion de los diferentes m ´ | odulos en la carcasa ´
Sistemas de sujecion de los m ´ | odulos, como pesta ´ | nas o pivotes a medida para el asiento de las ˜
placas o el ajuste a presion del sensor. ´

Ranuras de ventilacion pr ´ oximas al sensor con el objetivo de que el aire fluya con el menor impe- ´ dimento posible al interior del sensor y no interfiera en los valores medidos.

Agujeros para la salida de los conectores del modulo de alimentaci ´ | on y su conexi ´ | on al cable ´
del transformador sin abrir la carcasa, ademas de para el accionamiento del bot ´ | on ON/OFF del ´
modulo de alimentaci ´ | on. ´

Para el diseno de la carcasa se ha utilizado el software Rhinoceros 3D y se ha generado el archivo ˜
de modelado con la extension´ .3dm ademas de los ficheros ´ | .stl para su impresion, dichos ficheros se ´
encuentran adjuntos en el repositorio del proyecto [8].
La impresora 3d utilizada para su impresion ha sido la ´ | Creality Ender 3 Pro, a continuacion la figura ´
3.7 muestra unas imagenes con la carcasa modelada y el resultado obtenido. ´

22

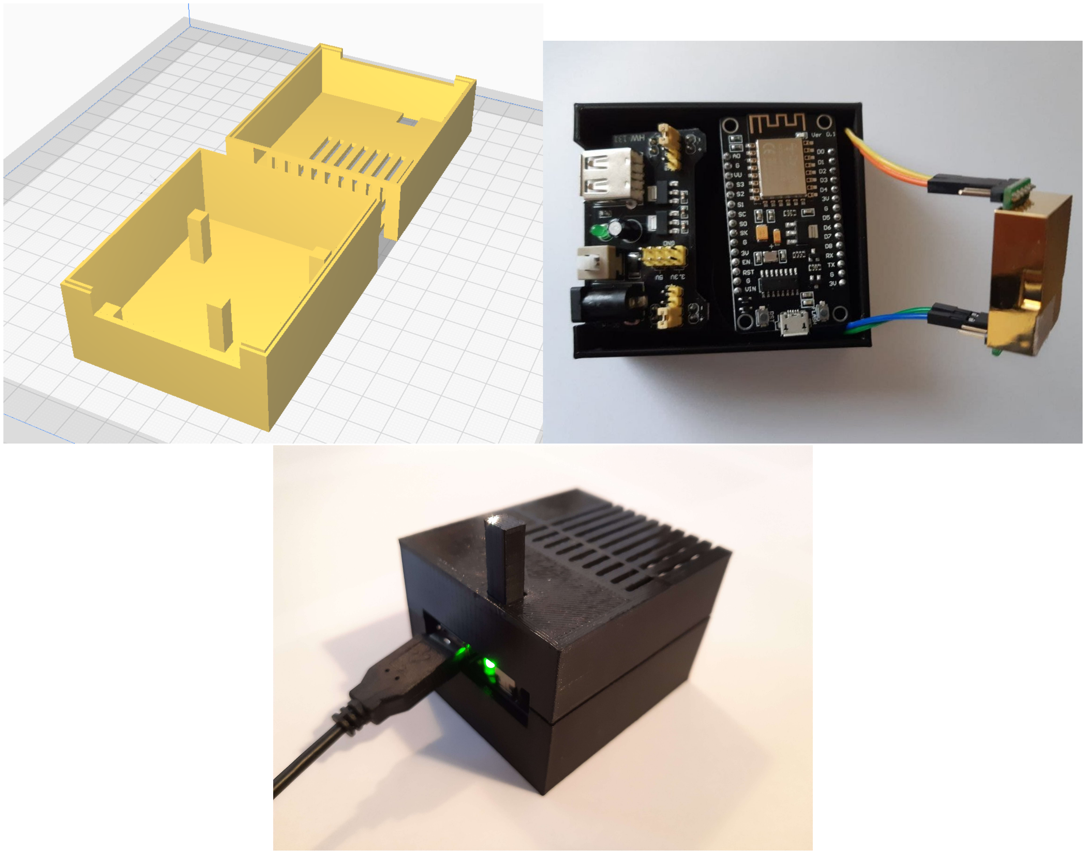
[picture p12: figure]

Figura 3.7: Carcasa impresa en 3D

## 4 Arquitectura Cloud

### 4.1 Instancia en servidor Amazon AWS

La recepcion, almacenamiento y tratamiento de los datos enviados por el sensor de CO2 se llevar ´ | á
a cabo en una instancia de maquina virtual haciendo uso de los servicios en la nube que la empresa ´ Amazon con su plataforma AWS ofrece para particulares y empresas.
En concreto para este proyecto de TFM se utilizara una instancia ´ | Amazon EC2 utilizando la capa
gratuita que proporciona durante el primer ano de uso de sus servicios, esto no supone un problema ˜ pues el servicio Amazon EC2 (Elastic Compute Cloud) permite el redimensionado de las características
tecnicas de la m ´ | aquina virtual de forma el ´ | astica a medida que aumente la demanda y el tr ´ | afico al ´
servidor.
| La capa gratuita permitira ejecutar una instancia de tipo ´ | | t2.micro con 1 CPU virtual, 1 GB de
memoria RAM y almacenamiento elastico EBS. ´
La distribucion a instalar para esta instancia ser ´ | á Ubuntu Server 20.04 y se accedera a ella para ´
el control remoto e instalacion de los servicios mediante una conexi ´ | on remota ´ | ssh utilizando el par de
claves publica/privada obtenido durante la creaci ´ | on de la instancia. ´

23

Por ultimo, ser ´ | a necesario establecer la apertura de puertos a internet de los servicios que se ne- ´
cesiten. Como se vera en la secci ´ | on´ 4.2 los puertos a abrir seran el 9000 para la escucha del broker ´
MQTT Mosquitto y los puertos 80 y 443 para las peticiones http y https al proxy inverso.

### 4.2 Despliegue de servicios

### 4.2.1 Arquitectura

La arquitectura a desplegar para la recogida, tratamiento y visualizacion de los datos enviados por ´
el sensor se llevara a cabo bajo el entorno de virtualizaci ´ | on en contenedores de Docker, lo que permite ´
realizar un despliegue automatico de todos los servicios con las configuraciones requeridas, como se ´
explicara en el apartado ´ | 4.2.2.

Los servicios a desplegar en el lado del servidor, todos ellos de software libre, son:

Backend, comprende la parte de conexion entre la recepci ´ | on de la informaci ´ | on del broker MQTT ´
y el almacenamiento de los datos en la BBDD, ver seccion´ 4.3, se utilizara el servicio de progra- ´
macion de flujos gr ´ | aficos de informaci ´ | on´ Node-Red.
Base de datos, almacena la informacion de la concentraci ´ | on de CO2 y de la temperatura como ´
series temporales de tiempo, timestamp - valor, se utilizara la base de datos de series tempo- ´ rales InfluxDB, ver seccion´ 4.4.
Frontend, comprende la parte de visualizacion gr ´ | afica de los valores registrados en la base de ´
datos, se utilizara el servicio ´ | Grafana que permite mediante consultas a las BBDD obtener los
valores del sensor en una determinada ventana de tiempo y mostrar los valores en diferentes tipos de dashboards, ver seccion´ 4.5.
Broker MQTT, se desplegara el broker ´ | Eclipse Mosquitto para que el sensor pueda publicar los
datos a el de forma securizada con usuario y contrase ´ | na de conexi ˜ | on al broker. ´
Proxy inverso, sera el encargado de redirigir el tr ´ | afico entrante ante peticiones http y https al ´
servicio escogido en funcion del subdominio indicado en la url, esto permite adem ´ | as de balancear ´
el trafico, abrir varios servicios web a internet sin necesidad de la apertura de puertos adicionales ´ con el consecuente riesgo que supondría para el servidor. El proxy inverso a utilizar será Caddy
que ademas permite de forma automatizada la generaci ´ | on de los certificados https mediante la ´
autoridad de certificacion gratuita ´ | Let’s Encrypt.

La siguiente figura 4.1 muestra un esquema de la arquitectura de servicios que conformara el servi- ´ dor.

### 4.2.2 Docker

Docker es un proyecto de codigo abierto que automatiza el despliegue de aplicaciones dentro de ´
contenedores de software, proporcionando una capa adicional de abstraccion y automatizaci ´ | on de vir- ´
tualizacion de aplicaciones en m ´ | ultiples sistemas operativos. ´

Un contenedor Docker, a diferencia de una maquina virtual, no requiere incluir un sistema operativo ´ independiente. En su lugar, se basa en las funcionalidades del kernel y utiliza el aislamiento de recursos (CPU, la memoria, el bloque E/S, red, etc.) y namespaces separados para aislar la vista de una

24

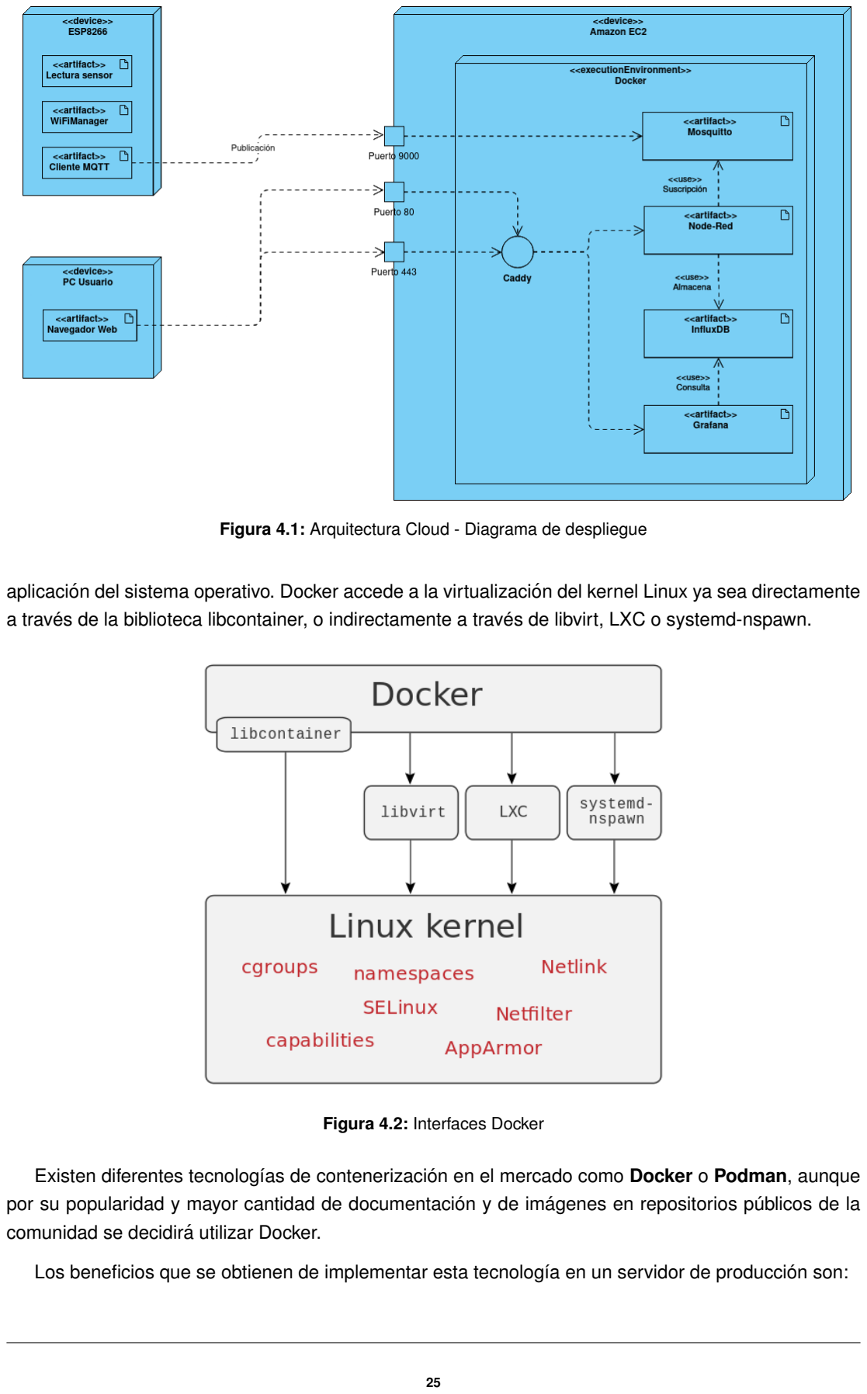
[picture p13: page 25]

Figura 4.1: Arquitectura Cloud - Diagrama de despliegue

aplicacion del sistema operativo. Docker accede a la virtualizaci ´ | on del kernel Linux ya sea directamente ´
a traves de la biblioteca libcontainer, o indirectamente a trav ´ | es de libvirt, LXC o systemd-nspawn. ´

Figura 4.2: Interfaces Docker

Existen diferentes tecnologías de contenerizacion en el mercado como ´ | | Docker o Podman, aunque
por su popularidad y mayor cantidad de documentacion y de im ´ | agenes en repositorios p ´ | ublicos de la ´
comunidad se decidira utilizar Docker. ´

Los beneficios que se obtienen de implementar esta tecnología en un servidor de produccion son: ´

25

Automatizacion de los despliegues de las aplicaciones ´ | , haciendo uso de ficheros Dockerfile
para crear la imagen y de ficheros docker-compose.yaml para el despliegue de todos los contenedores necesarios y variables de entorno que requiera la aplicacion. ´
Encapsulacion de versiones y dependencias ´ | | , permite tener imagenes de diferentes versiones ´
de la aplicacion, por lo que si ocurre alg ´ | un fallo en producci ´ | on con la ´ | ultima versi ´ | on desplegada, ´
simplemente es necesario levantar el contenedor de la version anterior para tenerla operativa en ´ segundos. Ademas al estar encapsulados las diferentes dependencias de cada contenedor per- ´
mite utilizar diferentes versiones de python, apache, php o demas servicios en la misma m ´ | aquina ´
sin riesgo de conflictos entre versiones.
Mayor seguridad, el codigo y los ficheros de configuraci ´ | on son encapsulados en la imagen de ´
docker por lo que supone una barrera de entrada adicional ante cualquier posible manipulacion´ del mismo durante un ataque informatico. ´
Mejor escalabilidad, el uso de contenedores permite una mejor segmentacion del c ´ | odigo de la ´
aplicacion y su orientaci ´ | on hacia microservicios, un tipo de arquitectura que permite una mejor ´
escalabilidad para aplicaciones grandes.

Mejor portabilidad, pudiendo facilmente trasladar las aplicaciones de un servidor a otro sin volver ´ a instalar todo, simplemente creando un nuevo contenedor a partir de la imagen.

Permite la implementacion con Kubernetes ´ | , una de las ventajas de usar kubernetes junto con
contenedores es la posibilidad de alojarlos en diferentes maquinas, lo que brinda la posibilidad de ´
utilizar una arquitectura de computacion distribuida, ideal para aplicaciones con mucho tr ´ | afico y ´
gran cantidad de datos a procesar (Big Data).

En general, las aplicaciones que utilizan la tecnología de contenerizacion con Docker emplean una ´ arquitectura como la que describe la figura 4.3.

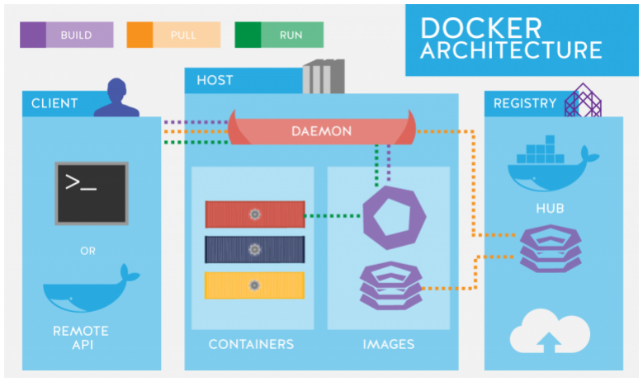
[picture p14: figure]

Figura 4.3: Arquitectura Docker

Dadas las numerosas ventajas que ofrece el uso de aplicaciones contenerizadas utilizando Docker,
y dado que es hacia donde se esta moviendo, con mucha aceptaci ´ | on actualmente, el mercado del ´

26

desarrollo de software, lo mas conveniente es utilizar este tipo de tecnolog ´ | ía para el despliegue de los
servicios de los que hara uso el sensor de CO2 inteligente, mejorando la escalabilidad y la portabilidad ´ del proyecto para futuras versiones y mejoras del producto.
Para la aplicacion actual se har ´ | a uso de servicios de software libre, por lo que no se contempla la ´
programacion a medida de una plataforma cloud para la gesti ´ | on de la informaci ´ | on enviada por el sensor. ´
Se desplegaran los servicios mediante la descripci ´ | on de los contenedores a trav ´ | es del fichero ´
docker-compose.yaml. (https://github.com/davidadrianrg/open-co2-monitoring-system/blob/master/docker-compose.yml)
En este fichero se describen las imagenes a descargar del repositorio de acceso p ´ | ublico ´ | Docker
HUB. Sera necesario indicar los puertos que queremos que el contenedor exponga a la m ´ | aquina, como ´
por ejemplo el puerto 9000 para el broker MQTT. Se estableceran las variables de entorno que utiliza- ´ ran los contenedores y que permiten realizar determinadas configuraciones como establecer usuarios
y contrasenas a los diferentes servicios, las variables de entorno se escribir ˜ | an en un fichero oculto aso- ´
ciado .env para mayor seguridad. Por ultimo tambi ´ | en se establecen los vol ´ | umenes a compartir entre ´
los contenedores y la maquina host, para asegurar la persistencia de los datos y un f ´ | acil acceso a los ´
mismos.
Una vez finalizada la configuracion del despliegue ser ´ | a necesario ejecutar el siguiente comando en ´
una terminal para levantar todos los contenedores con funcionamiento en segundo plano (detached).

sudo docker-compose up -d

En este momento Docker descargara las im ´ | agenes de ´ | Docker HUB y levantara los contenedores ´
con las configuraciones indicadas, se puede comprobar el estado de los mismos mediante el siguiente comando.

sudo docker ps

### 4.3 Backend con Node-Red

Se entiende por Backend la parte de un servicio, como una pagina web, encargada de la l ´ | | ogica y ´
que suele llevarse a cabo en un servidor.

En el caso del sistema IoT de monitorizacion de la calidad del aire que es objeto de este TFM, el ´ backend sera el encargado de recoger todos los datos del sensor (CO2 y Temperatura) que llegan a ´
traves del broker MQTT, hacer las transformaciones necesarias seg ´ | un el modelo de datos de la base ´
de datos y almacenarlos en esta. ´
Como Backend para este sistema se ha decidido utilizar el servicio de codigo libre ´ | | Node-Red que
es una herramienta de programacion visual basada en diagramas de flujo y desarrollada por la empresa ´ IBM.

Con este tipo de programacion pueden conectarse diferentes dispositivos hardware IoT de forma ´
sencilla, con otros servicios web que expongan su API de forma publica. Adem ´ | as, ´ | Node-Red cuenta
con una gran cantidad de nodos creados por numerosos desarrolladores que permiten su integracion´ directa con otros servicios conocidos, como los broker MQTT o conectores para bases de datos.

La siguiente figura 4.4 muestra el diagrama de flujo realizado para este sistema de monitorizacion´ de la calidad del aire.

27

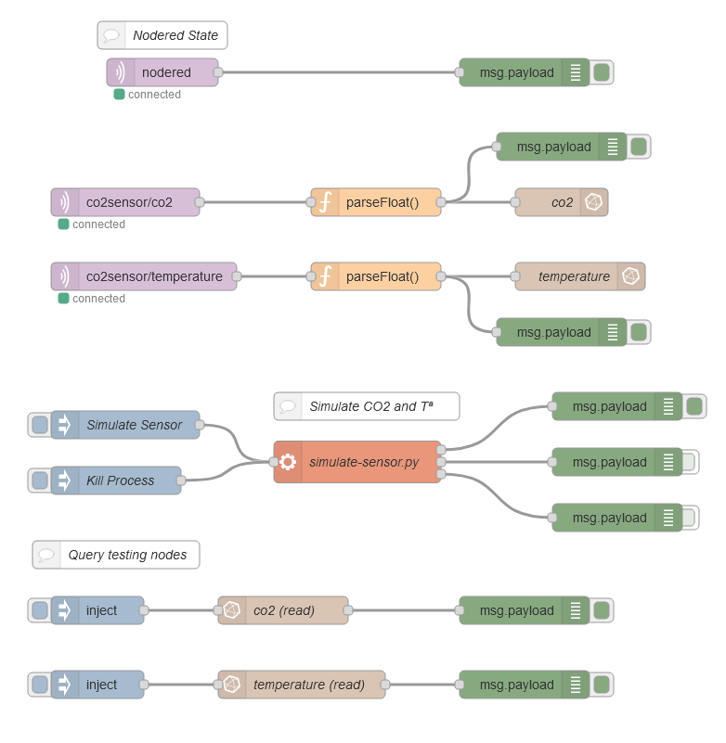
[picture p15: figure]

Figura 4.4: Diagrama de flujo en Node-Red

A continuacion se describir ´ | a cada flujo de forma detallada comenzando de arriba a abajo. ´

Flujo de estado, se suscribe al broker MQTT y lee el topic nodered que se ha configurado para
publicar el estado de conexion del cliente Node-Red al broker MQTT, el mensaje del topic lo env ´ | ía
a un nodo debug para mostrarlo por consola.

Flujo de lectura/escritura de CO2, se suscribe al topic co2sensor/co2 en el cual se publican
los valores de concentracion de CO2 en ppm, el payload recibido es ´ | parseado de tipo String a
tipo Float y posteriormente es enviado al nodo de la base de datos InfluxDB que guardara ese ´ valor en el bucket (equivalente a base de datos) llamado smart-co2-sensor y como medicion´ co2, ademas el payload convertido a float es enviado a un nodo debug para su visionado por consola. ´

Flujo de lectura/escritura de Temperatura, se trata de un flujo similar al anterior en funcionamiento, pero en este caso el topic a suscribirse es co2sensor/temperature y se escribira en la ´ BBDD en el mismo bucket pero como medicion´ temperature.

Flujo de simulacion´ , se trata de un flujo que activa de forma manual mediante los nodos input un script desarrollado en python, simulate-sensor.py, (https://github.com/davidadrianrg/open-co2-monitoring-system/blob/master/test/simulate-sensor.py) que se encarga de generar de forma aleatoria
mediante una distribucion normal valores de temperatura y concentraci ´ | on de CO2 y publicarlos al ´
broker MQTT, de esta forma puede comprobarse el funcionamiento de los servicios del servidor de forma aislada al funcionamiento y datos que envía el sensor real.

Flujo de consulta de CO2, se trata de un flujo que se activa de forma manual mediante un
nodo input y activara un nodo de consulta de la base de datos que devolver ´ | a los valores de la ´

28

ultima hora de concentraci ´ | on de CO2 y los mostrar ´ | a por consola, ´ | util para comprobar el correcto ´
almacenamiento de los valores en la base de datos.

Flujo de consulta de Temperatura, se trata de un flujo similar al anterior que devuelve los valores de temperatura de la ultima hora y los muestra por consola. ´

Los flujos antes mencionados constituyen la logica del servidor y permiten hacer las operaciones de ´
mantenimiento y busqueda de errores mediante los flujos de simulaci ´ | on y consulta. ´

### 4.4 BBDD de series temporales

Dadas las características de los datos a almacenar, valores fluctuantes con el tiempo, se ha decidido
utilizar un tipo de base de datos disenada espec ˜ | íficamente para tal fin en lugar de usar una base de
datos de tipo relacional SQL.

Entre las ventajas que supone utilizar este tipo de bases de datos frente a las bases de datos relacionales estan las siguientes: ´

Mejor escalabilidad, las bases de datos NoSQL de series temporales tienen una mejor escalabilidad al utilizar almacenamiento de datos de tipo clave-valor en lugar de tablas estructuradas.

Mejor velocidad, la insercion de datos es m ´ | as eficiente y r ´ | apida en este tipo de bases de datos ´
lo que permitiría almacenar mas datos por segundo, aumentando la frecuencia de muestreo. ´
Esquemas dinamicos ´ | , el esquema no tiene que ser predefinido previamente durante el disenõ
de la base de datos, es posible por ejemplo anadir un nuevo sensor y que utilice un esquema de ˜ valores diferente mas adaptado al mismo. ´

La base de datos escogida para este proyecto ha sido InfluxDB una base de datos de codigo abierto ´
de tipo series temporales disenada especificamente para aplicaciones del ˜ | | Internet of Things y que
presenta un gran numero de conectores para diferentes lenguajes de programaci ´ | | on como Javascript o ´
Python ademas de otros servicios de visualizaci ´ | on de datos como ´ | AWS Cloudwatch o Grafana.

Utiliza un lenguaje de consulta de tipo scripting denominado Flux inspirado en Javascript. En este tipo de base de datos, los datos se almacenan en unas estructuras llamadas buckets con estructura del tipo clave-valor.

Las consultas utilizadas para la visualizacion de los datos, mediante el lenguaje ´ | | Flux siguen una
estructura similar a la siguiente:

from(bucket: "smart-co2-sensor")

|> range(start: -1h)

|> filter(fn: (r) =>

r._measurement == "co2"
)
Esta consulta devolvera los valores de ppm de CO2 junto con su ´ | índice de tiempo (timestamp) de la
ultima hora desde el momento en que se ejecuta la consulta. ´

29

### 4.5 Frontend

Se entiende por Frontend la parte de un servicio, como una pagina web, encargada de la interfaz ´ grafica de usuario, es la parte visual de todo el servicio y debe garantizar la simplicidad de uso suficiente ´ para una correcta interaccion con el usuario. ´

El sistema planteado en este trabajo consta de dos interfaces de interaccion con el usuario, una ´
interfaz de visualizacion de dashboards con diferentes gr ´ | aficas para los valores de concetraci ´ | on de ´
CO2 y de Temperatura, y la recepcion de notificaciones a trav ´ | es del chat de mensajer ´ | ía Telegram.

### 4.5.1 Dashboards de visualizacion con Grafana ´

El servicio de visualizacion de dashboards de c ´ | odigo libre ´ | Grafana permite la visualizacion de datos ´
y metricas a trav ´ | es de cuadros de mando mediante consultas a m ´ | ultiples fuentes (bases de datos). ´
Para el presente proyecto se creara un dashboard denominado ´ | Smart CO2 Sensor Dashboard que
se puede observar en la figura 4.5.

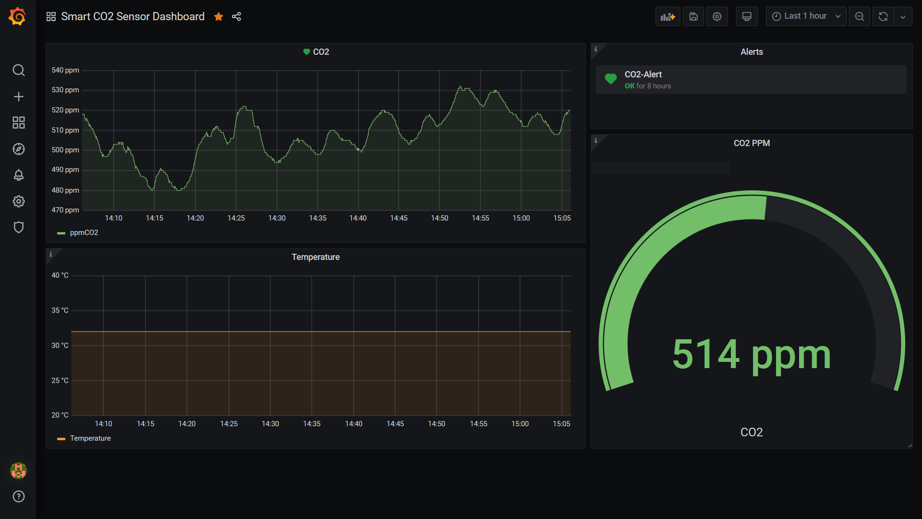
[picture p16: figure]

Figura 4.5: Dashboard en Grafana

Se pueden visualizar los datos de la ultima hora del dashboard en tiempo real accediendo al citado ´ enlace [1].

El dashboard esta formado por cuatro paneles de mando, a la izquierda se muestra la visualizaci ´ | on´
de las graficas temporales de la concentraci ´ | on de CO2 en partes por mill ´ | on´ (ppm) y a la grafica de ´
variacion de la temperatura en grados ´ | Celsius(ºC). A la derecha se muestra un medidor en tiempo real
de la concentracion de CO2 y un panel de alertas sobre dicha concentraci ´ | on. ´
La alerta esta configurada para disparar cuando se sobrepasen los 1000 ppm de concentraci ´ | on de ´
CO2 medidos por el sensor como valor medio en los ultimos 5 minutos. Esta alerta cambiar ´ | a el color de ´
la notificacion en el panel de alertas y el gr ´ | afico pasar ´ | a a tener fondo rojizo hasta volver a la normalidad ´
(por debajo de 1000 ppm). Ademas, se enviar ´ | a la notificaci ´ | on a trav ´ | es de un bot de notificaciones en ´

30

Telegram, como se explica en el apartado 4.5.2.

### 4.5.2 Bot de notificaciones en Telegram

Una de las funcionalidades que incorpora de forma integrada Grafana es la de enviar las alertas
mediante un bot de mensajería de la aplicacion´ Telegram, algo muy util pues notificar ´ | a en todo mo- ´
mento en un chat personal o un chat grupal a las personas de que el nivel de CO2 ha excedido el
maximo recomendado por lo que no ser ´ | a necesario que alguien se encuentre observando el dashboard ´
de Grafana para percatarse de dicha alerta.
De esta forma se puede asegurar una rapida intervenci ´ | on, como la apertura de ventanas en la sala, ´
para evitar que los niveles de concentracion de CO2 contin ´ | uen en aumento. ´
Para configurar el bot de notificaciones sera necesario crear un nuevo bot mediante la utilidad ´ | Bot
Father implementada por defecto en Telegram, solicitaremos la creacion de un nuevo bot y obtendre- ´ mos un API TOKEN que deberemos introducir en la configuracion de ´ Grafana de dicho bot, ademas´ deberemos introducir el id de usuario de Telegram o del chat grupal donde queramos que se envíen
las alertas, los bots son publicos en este chat de mensajer ´ | ía pero limitando su uso mediante el id men-
cionado, solo podr ´ | an interactuar con ellos el usuario con esa id o el chat grupal en caso de ser un id de ´
chat grupal.
La figura 4.6 muestra una imagen de la recepcion de las alertas en este chat de mensajer ´ | ía.

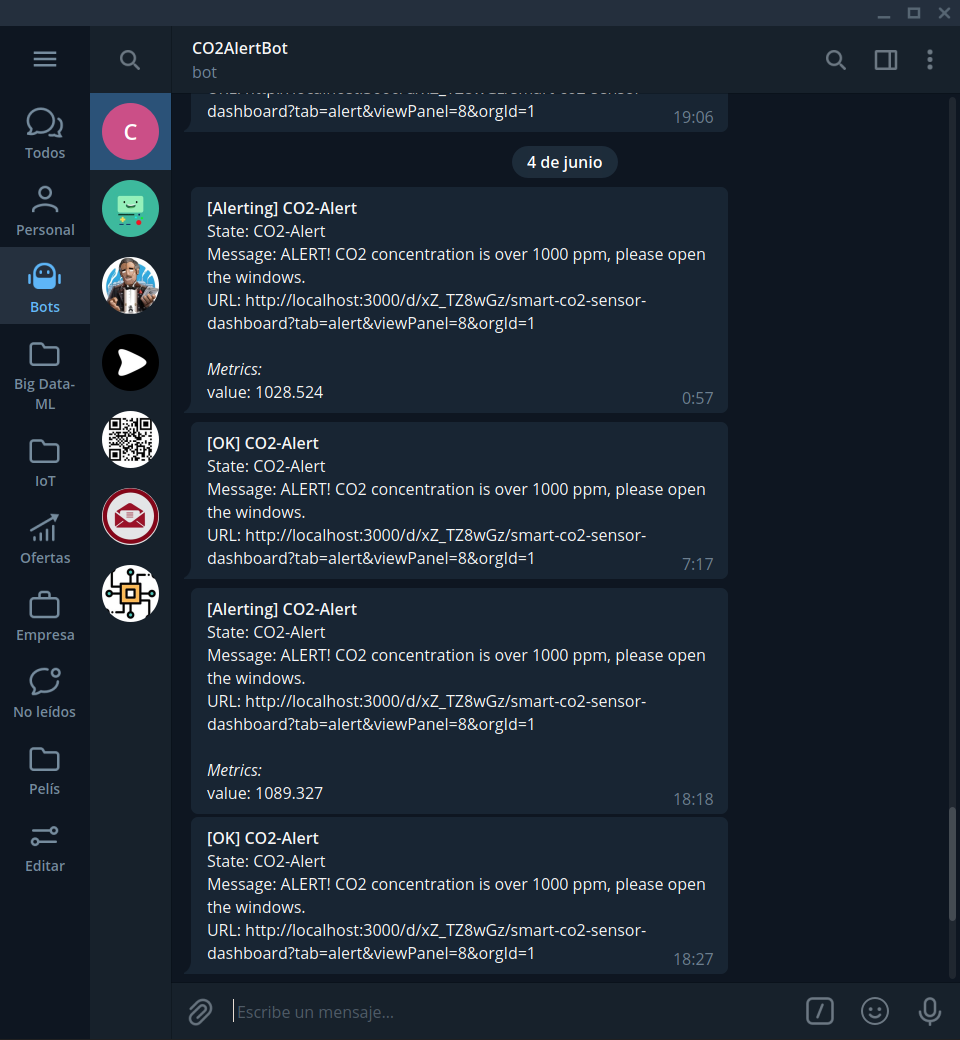
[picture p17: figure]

Figura 4.6: Bot de alertas en Telegram

31

## 5 Conclusiones y propuestas de mejora

### 5.1 Conclusiones y resultados obtenidos

Los resultados obtenidos de este proyecto de sensor de CO2 inteligente permiten demostrar la posibilidad de desarrollar un sistema de monitorizacion de la calidad del aire de bajo coste utilizando ´ tecnologías de software y hardware libre.

Los principales problemas encontrados durante el desarrollo del proyecto han sido:

Los plazos de entrega del sensor de CO2, al ser un producto de fabricante chino, el plazo de entrega puede ser de hasta 1 semana superior al de sus competidores.

La medicion de temperatura del sensor no es demasiado precisa al inferirla ´ | | | este mediante la ´
medicion directa de la concentraci ´ | on de CO2. ´

Debido a que el sensor utiliza tecnología NDIR, la ventilacion de la carcasa debe asegurar un ´
correcto flujo de aire en el, limitando el dise ´ | no de la misma. ˜

El elevado consumo tanto del microcontrolador como del sensor hacen inviable una solucion ali- ´ mentada por baterías.

En conclusion, el producto obtenido de este trabajo es un prototipo funcional que muestra como ´ juntando diferentes tecnologías puede hacerse un producto accesible, y que permite mejorar la calidad
del aire de locales cerrados mediante la notificacion y previsi ´ | on de la concentraci ´ | on de CO2, evitando ´
con ello la transmision de enfermedades respiratorias y el cansancio que altos niveles de concentraci ´ | on´
provocan en las personas.

### 5.2 Propuestas de mejora

El objetivo de este apartado es proponer una serie de mejoras que permitan en el futuro desarrollar
una version comercial del prototipo dise ´ | nado en este Trabajo Fin de M ˜ | aster y solucionar los problemas ´
detectados en el apartado 5.1.

Entre las mejoras que se recomienda implementar de cara a obtener un producto final estan: ´

Diseno de una placa PCB a medida. ˜

Anadir un sensor de temperatura y humedad integrado. ˜

Redisenar la carcasa seg ˜ | un los est ´ | andares est ´ | eticos del mercado y teniendo en cuenta las carac- ´
terísticas de ventilacion requeridas. ´

Asegurar un suministro continuo, fiable y un cierto stock de sensores de CO2 para evitar problemas con los plazos de entrega.

Mejorar el portal cautivo anadiendo m ˜ | as posibilidades de configuraci ´ | on y una est ´ | etica m ´ | as comer- ´
cial.
Diseno de una interfaz frontend a medida tanto para plataformas m ˜ | oviles como para el navegador ´
web.

32

En caso de optar por integrar alimentacion con bater ´ | ías, utilizar un microcontrolador con protocolo
Bluetooth Low Energy (BLE), el volcado de datos a la nube se hara a trav ´ | es de la comunicaci ´ | on´
con el smartphone que actuara de pasarela a internet. ´

Estas son algunas de las mejoras que se podrían implementar en el desarrollo de un producto final,
sin descuidar otros aspectos menos tecnicos como una correcta campa ´ | na de marketing y publicidad, ˜
un buen servicio de soporte al cliente y un sistema logístico de distribucion adecuado. ´

33

## 6 Referencias

[1] Grafana Labs Company. | Dashboard smart co2 sensor. | https://grafana.smartco2.

duckdns.org/d/xZ_TZ8wGz/smart-co2-sensor-dashboard?orgId=1&from=1622722761841&
to=1622726361842, (https://grafana.smartco2.duckdns.org/d/xZ_TZ8wGz/smart-co2-sensor-dashboard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) 2021. | Configurado por David Adrian Rodr ´ | íguez García (Usuario: demo,
Contrasena: demo). ˜
[2] Nick O’Leary et al. Librería pubsubclient para arduino. https://pubsubclient.knolleary.net/, 2009. Librería para la comunicacion MQTT utilizando el entorno Arduino. ´
[3] WifWaf et al. Librería mh-z19 para arduino. https://github.com/WifWaf/MH-Z19, 2019. Librería para microcontroladores Arduino y Espressif para la comunicacion con la familia de sensores MH- ´ Z19 de Winsen.
[4] Texas Instruments Inc. KeyStone Architecture Universal Asynchronous Receiver/Transmitter (UART) User Guide. Texas Instruments Inc., Dallas, TX, USA, 2010.
[5] Shenzhen Ai-Thinker Technology Co. Ltd. Ficha tecnica soc esp-12f. ´ | https://docs.ai-thinker.

com/_media/esp8266/docs/esp-12f_product_specification_en.pdf, (https://docs.ai-thinker.com/_media/esp8266/docs/esp-12f_product_specification_en.pdf) 2018.

[6] Zhengzhou | Winsen | Electronics | Technology | Co. | Ltd. | Ficha | tecnica | sensor | de ´
co2 | mh-z19c. | https://www.winsen-sensor.com/d/files/infrared-gas-sensor/

mh-z19c-pins-type-co2-manual-ver1_0.pdf, (https://www.winsen-sensor.com/d/files/infrared-gas-sensor/mh-z19c-pins-type-co2-manual-ver1_0.pdf) 2020.

[7] MQTT.org. Web oficial organizacion mqtt. ´ | https://mqtt.org/, 2020.
[8] David Adrian Rodr ´ | íguez García. | Open co2 monitoring system. | https://github.com/

davidadrianrg/open-co2-monitoring-system, (https://github.com/davidadrianrg/open-co2-monitoring-system) 2021. Proyecto de sistema para la monitoriza-
cion de CO2 mediante hardware IoT de bajo coste y servicios cloud de c ´ | | | | | | | odigo abierto para el ´
tratamiento, almacenamiento y visualizacion de los datos. ´
[9] PCE Iberica S.L. Ficha t ´ | ecnica medidor de co2 pce-cmm5. ´ | https://www.pce-instruments.com/

espanol/api/getartfile?_fnr=1504204&_dsp=inline. (https://www.pce-instruments.com/espanol/api/getartfile?_fnr=1504204&_dsp=inline)

[10] tzapu et al. Librería wifimanager. https://github.com/tzapu/WiFiManager, 2018. Librería para
la gestion de la conexi ´ | on WiFi en el microcontrolador ESP8266 mediante portal cautivo. ´
[11] María Cruz Minguillon Xavier Querol Jos ´ | e Manuel Felisi y Tom ´ | as Garrido. ´ | Guía para ventilacion en ´
aulas. Version 3. CSIC-IDAEA, Ministerio de Ciencia e Innovaci ´ | on y Mesura, Espa ´ | na, 2020. ˜
[12] Miguel Angel Casanova. Proyecto codos. ´ | https://github.com/miguelangelcasanova/codos,

2020. Proyecto CODOS para la monitorizacion de la calidad del aire con hardware de bajo coste. ´

34

## Anexos

### Listado de materiales

A continuacion se adjuntan en la tabla ´ | 6.1 el listado de materiales electronicos, inform ´ | aticos y soft- ´
ware utilizados.
Referencia | Descripcion | Cantidad | Proveedor ´
Sensor MH-Z19c | Sensor de concentracion de CO2 con tecnolog ´ | ía NDIR | 1 | Aliexpress - Winsen
NodeMCU V3 | Placa de desarrollo IoT con SoC ESP8266 | 1 | Amazon - AZDelivery
MB-102 | Modulo de alimentaci ´ | on 3.3V/5V | 1 | Amazon - AZDelivery ´
Cable Dupont | Cable para la interconexion entre m ´ | odulos | 6 | Amazon - SODIAL ´
Creality Ender 3 Pro | Impresora 3D | 1 | Aliexpress - Creality
Plastico PLA Negro | Filamento PLA para la impresi ´ | on de la carcasa | 0,05 | Amazon - Geeetech ´
Amazon EC2 | Instancia de servidor t2.micro en Amazon AWS | 1 | Amazon
Docker | Software de virtualizacion en contenedores | 1 | Docker ´
Node-Red | Software de programacion gr ´ | afica basada en flujos | 1 | JSFoundation - IBM ´
Eclipse Mosquitto | Broker MQTT | 1 | Eclipse Foundation
InfluxDB | Base de datos de series temporales | 1 | InfluxData
Grafana | Software para la visualizacion de paneles de control | 1 | Grafana Labs ´
Bot de Telegram | Bot para la notificacion de alertas | 1 | Telegram ´
Caddy | Proxy inverso con encriptacion https autom ´ | atica | 1 | Stack Holdings ´

Tabla 6.1: Listado de materiales empleados.

35

## Presupuesto

A continuacion se muestra en la tabla ´ | 6.2 una estimacion del presupuesto del proyecto. ´
Referencia | Cantidad | Unidad | | Precio unitario | Precio Total
Sensor MH-Z19c | 1 | ud | | 17,09 C | 17,09 C
NodeMCU V3 | 1 | ud | | 7,99 C | 7,99 C
MB-102 | 1 | ud | | 3,99 C | 3,99 C
Cable Dupont | 6 | ud | | 0,09 C | 0,53 C
Creality Ender 3 Pro | 1 | ud | | 175,00 C | 175,00 C
Plastico PLA Negro | 0,05 | kg | 20,00 ´ | C | 1,00 C
Amazon EC2 (capa gratuita) | 1 | ud | - C | - C
Ingeniero Informatico Industrial | 60 | h | 30,00 ´ | C | 1.800,00 C
Total Ejecucion Material | 2.005,60 ´ | C
13 % Gastos generales | | | | | 260,73 C
6 % Beneficio industrial | | | | | 120,34 C
Importe de Ejecucion | 2.386,67 ´ | C
21 % I.V.A. | | | | | 501,20 C
Importe de Contrata | | | | | 2.887,87 C

Tabla 6.2: Presupuesto de prototipo de sensor inteligente de CO2

Ascendiendo el presupuesto general a la expresada cantidad de DOS MIL OCHOCIENTOS OCHEN-
TA Y SIETE EUROS CON OCHENTA Y SIETE CENTIMOS (2.887,87 ´ | C).

36

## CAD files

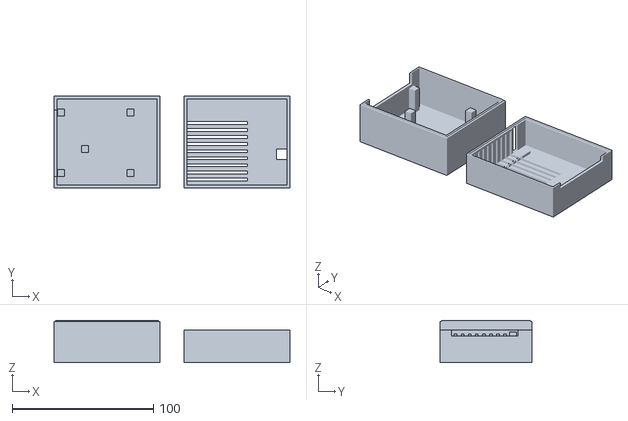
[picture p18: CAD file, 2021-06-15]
case/case_print.stl
167.0 x 65.0 x 30.0

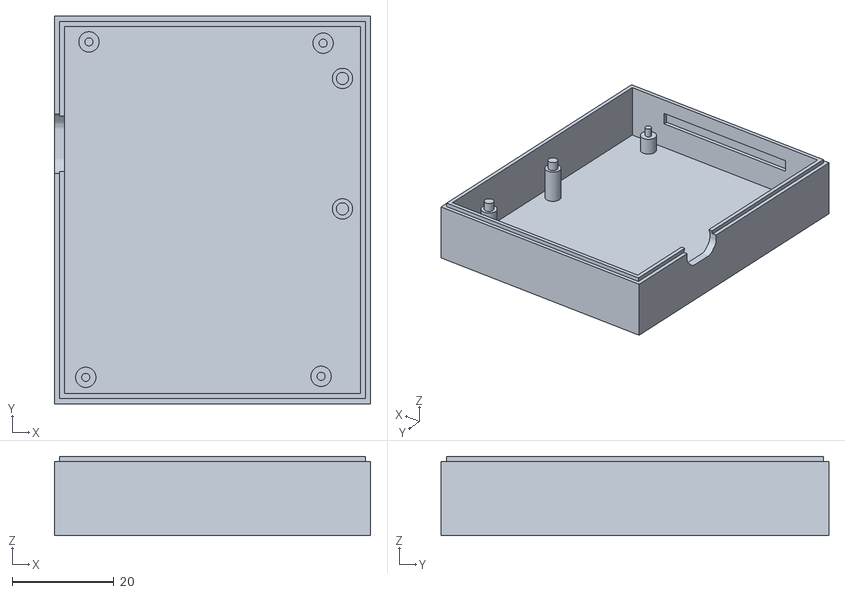
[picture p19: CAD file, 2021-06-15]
case/case_print2.stl
62.0 x 76.1 x 15.5

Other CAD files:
case/case_model.3dm

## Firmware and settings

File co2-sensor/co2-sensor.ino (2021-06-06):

/*
Open CO2 Monitoring System
Air Quality Monitoring System for rooms with limited ventilation
ESP8266 MCU and MH-Z19C sensor
MQTT CO2 ppm data publishing

Author: David Adrián Rodríguez García
*/

#include <ESP8266WiFi.h>    //Library to connect WiFi
#include <WiFiManager.h>    //Library to make an AP to introduce WiFi credentials
#include <MHZ19.h>          //Library to manage CO2 sensor
#include <SoftwareSerial.h> //Library to use another pins than RX and TX to UART communication
#include <PubSubClient.h>   //Library to manage MQTT connection to the broker
#include "keys.h"            //File containing the brokerIP, brokerPort, mqtt_user and mqtt_password

#define RX_PIN 4
#define TX_PIN 5
#define clientId "Smart-CO2-Sensor"
#define mqtt_topic "mqtt"                        //This is the [root topic]
#define co2Topic "co2sensor/co2"                 //MQTT topic to publish CO2 ppm values
#define temperatureTopic "co2sensor/temperature" //MQTT topic to publish temperature values
#define samplingTime 120000                     //Setting the sampling time to measure CO2

MHZ19 myMHZ19;                             // Constructor for MHZ19 library
SoftwareSerial softSerial(RX_PIN, TX_PIN); // Create a software serial instead of using hardware serial
WiFiClient espClient;                      //Intializing WiFi Client
PubSubClient client(espClient);            //Intializing MQTT client

//Counter to take into account the time delay between different CO2 acquisition values
unsigned long timer = 0;

//Char variables for the mqtt messages
char msg_co2[6];
char msg_temperature[3];

//Function to setup sensor
void setupSensor()
{
    //Start serial communication
    softSerial.begin(9600);
    //Start the comunication with the sensor
    myMHZ19.begin(softSerial);
    // Turn auto calibration ON (OFF autoCalibration(false))
    myMHZ19.autoCalibration();
}

void setupWiFi()
{
    //Start Wifi communication setup
    WiFi.mode(WIFI_STA);

    //WiFiManager, Local intialization. Once its business is done, there is no need to keep it around
    WiFiManager wm;

    //Reset settings - wipe credentials for testing
    //wm.resetSettings();

    // Automatically connect using saved credentials,
    // if connection fails, it starts an access point with the specified name ("Smart-CO2-Sensor"),
    // then goes into a blocking loop awaiting configuration and will return success result

    bool res;
    res = wm.autoConnect("Smart-CO2-Sensor"); // AP without password
    //res = wm.autoConnect("AutoConnectAP", "password"); // Password protected AP

    if (!res)
    {
        Serial.println("Failed to connect");
        ESP.restart(); //Restarting the esp8266 in order to try again WiFi matching
    }
    else
    {
        //WiFi Connected to the microcontroller
        Serial.println("Connected to the WiFi");
    }
}

void reconnect()
{
    // Loop until device is connected to the broker
    while (!client.connected())
    {
        Serial.print("Attempting MQTT connection...");
        // Attempt to connect
        if (client.connect(clientId, mqtt_username, mqtt_password))
        {
            Serial.println("connected");
            // Once connected, publish an announcement...
            client.publish(mqtt_topic, "connected");
        }
        else
        {
            Serial.print("failed, rc=");
            Serial.print(client.state());
            Serial.print(" wifi=");
            Serial.print(WiFi.status());
            Serial.println(" try again in 5 seconds");
            // Wait 5 seconds before retrying
            delay(5000);
        }
    }
}

void callback(char *topic, byte *payload, unsigned int length)
{
    //TODO MQTT Callback, pending to implement if needed
}

void setup()
{
    Serial.begin(115200);

    //Setting up the sensor communication
    setupSensor();

    //Setting up WiFi communication
    setupWiFi();

    //Setting up MQTT connection with the broker
    client.setServer(brokerIP, brokerPort);
    client.setCallback(callback);
}

void loop()
{
    //Confirm if is still connected to mqtt broker
    if (!client.connected())
    {
        reconnect();
    }
    //Implement MQTT loop to receive incoming mesagges
    client.loop();
    //Take a new CO2 value each 2 seconds
    if (millis() - timer >= samplingTime)
    {

        // Get the CO2 ppm values from the sensor
        int ppmCO2 = myMHZ19.getCO2();

        // Print the CO2 level on serial monitor
        Serial.print("CO2 (ppm): ");
        Serial.println(ppmCO2);

        // Take current temperature value
        int temperature = myMHZ19.getTemperature();

        // Print temperature on serial monitor
        Serial.print("Temperature (C): ");
        Serial.println(temperature);

        //Parsing data for the mqtt payload
        snprintf(msg_co2, 6, "%i", ppmCO2);
        snprintf(msg_temperature, 3, "%i", temperature);

        //Publishing CO2 and Temperature values to the broker
        client.publish(co2Topic, msg_co2);
        client.publish(temperatureTopic, msg_temperature);

        // Updating time value to control acquisition time loop
        timer = millis();
    }
}

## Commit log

2021-03-14 Fixing some minor issues
    [co2-sensor.ino]
2021-06-06 Changed sampling time according to sensor's response time
2021-06-15 Added 3D printed case as enclosure to the hardware
    [case_model.3dm, case_print.stl, case_print2.stl]
2021-06-27 Cambiando permisos de archivo passwd
